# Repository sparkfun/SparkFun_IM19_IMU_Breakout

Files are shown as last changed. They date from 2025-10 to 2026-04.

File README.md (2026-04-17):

SparkFun 9DoF IMU Breakout - IM19
========================================

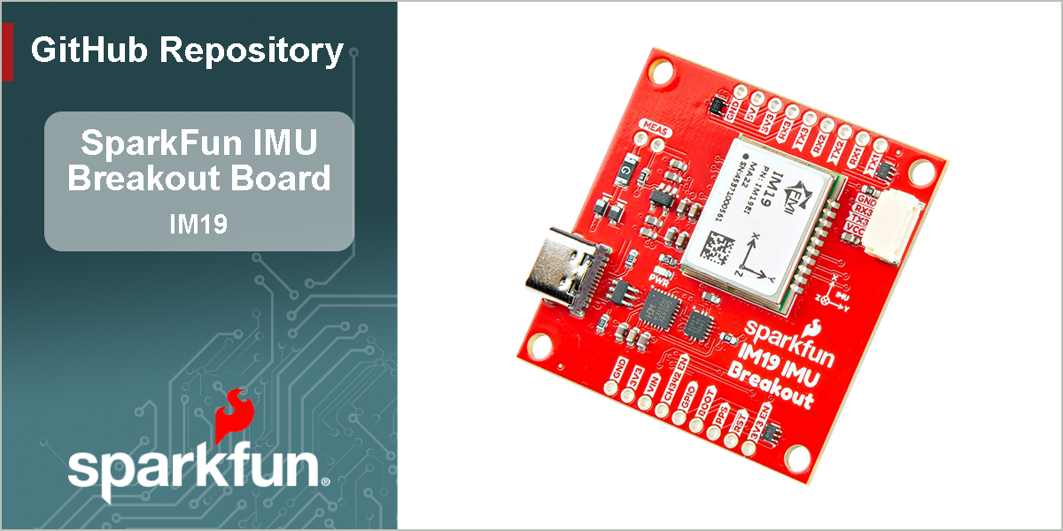
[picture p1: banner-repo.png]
SparkFun 9DoF IMU Breakout - IM19


[*SparkFun 9DoF IMU Breakout - IM19 (SEN-30381)*](https://www.sparkfun.com/sparkfun-9dof-imu-breakout-im19.html)

The Feyman (FMI) IM19 attitude module combines MEMS sensor data with GNSS RTK positioning data to provide high-precision attitude measurements. This enables advanced features, like tilt-compensated surveying and robust navigation through brief GNSS outages.

- **Survey-Grade Accuracy:** Delivers roll and pitch measurements accurate to within 0.05 degrees.
- **Tilt Compensation:** No more perfectly vertical survey poles! The IM19 can calculate a virtual digital level point at any tilt angle, revolutionizing field data collection.
- **Sensor Fusion:** Offers a continuous navigation solution (Dead Reckoning) even during brief GNSS signal loss, making it ideal for urban or obstructed environments.

When fed with NMEA **`GGA`**, **`GST`**, and **`RMC`** messages at **5Hz**, and a standard **Pulse-Per-Second timing signal**, the IM19 attitude module will output a proprietary NMEA ASCII `GPFMI` message which contains the compensated position of the tip of your surveying pole, plus the Roll, Pitch and Yaw of the IMU itself.

Our Breakout provides access to all three IM19 UART interfaces. `UART1` and `UART2` are accessible via a CH342 dual-channel USB-UART interface. `UART3` is accessible via a 4-pin locking JST connector. All three UARTs can be accessed via breadboard-compatible breakout pads too. The CH342 can be disconnected by simply pulling the `CH342_EN` breakout pad low; allowing full access to `UART1` and `UART2` via the breakout pads.

Power can be provided by USB, or the `VIN` (5V nominal) breakout pad. With care, you can also connect an external 3.3V supply to the `3V3` breakout pads or `Pin 1` of the JST connector. A jumper allows JST `Pin 1` to be configured for 5V input / output.

The IM19 attitude module is centered on the center of the PCB, simplifying your LEVER_ARM calculations. There is no X,Y offset to consider. The Z origin is 1.6mm above the top surface of the PCB (inside the IM19 module package); 3.2mm above the bottom surface of the PCB.

The 1.7" x 1.7" PCB is the same size as some of our RTK GNSS Boards, making it easy to stack the IM19 above or below your existing GNSS breakout board.

> [!NOTE]
> The IM19 needs to be fed with GNSS positioning data with a RTK Fixed solution *(RTK Fix)* in order to work correctly. This board will not work with non-RTK GNSS receivers.

Documentation
-------------

- **[Hookup Guide (docusaurus)](http://docs.sparkfun.com/SparkFun_IM19_IMU_Breakout/)** - A hookup guide for the SparkFun IM19 IMU breakout board hosted by GitHub pages.<br>
	 

Repository Contents
-------------------

- **[/docs](/docs/)** - Online documentation files
	- [/assets](/docs/assets/) - Assets files
		- [/3d_model](/docs/assets/3d_model/) - 3D models for the board
		- [/board_files](/docs/assets/board_files/) - Design files for the board
			- [KiCad Design Files](/docs/assets/board_files/kicad_files.zip) (.zip)
			- [Schematic](/docs/assets/board_files/schematic.pdf) (.pdf)
			- [Dimensions](/docs/assets/board_files/dimensions.pdf) (.pdf)
		- [/component_documentation](/docs/assets/component_documentation/) - Datasheets for hardware components
		- [/img/hookup_guide](/docs/assets/img/hookup_guide/) - Images for hookup guide documentation - Hookup guide images for the board
		- /Hardware - Hardware design files (.brd, .sch)
			- /Production - Production files

Product Variants
----------------

- [SEN-30381](https://www.sparkfun.com/sparkfun-9dof-imu-breakout-im19.html) - IM19 IMU Breakout

Version History
---------------

- [v10](https://github.com/sparkfun/SparkFun_IM19_IMU_Breakout/releases/tag/v10) - Initial Release

License Information
-------------------

This product is ***open source***!

Please review the [`LICENSE.md`](./LICENSE.md) file for license information.

If you have any questions or concerns about licensing, please contact technical support on our [SparkFun forums](https://community.sparkfun.com/).

Distributed as-is; no warranty is given.

- Your friends at SparkFun.

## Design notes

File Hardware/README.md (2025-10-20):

SparkFun <PRODUCT NAME> Design Files
=====================================

The .kicad_sch and .kicad_pcb files here are KiCad schematic and PCB design files from SparkFun Electronics.
KiCad can be found [here](https://www.kicad.org/).

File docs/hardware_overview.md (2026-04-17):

---
title: Hardware Overview
description: Overview of the board design, components, and interfaces
---

import Link from '@docusaurus/Link';

## Board Layout
The SparkFun 9DoF IMU Breakout - IM19 features the following:

<figure>
Layout
<figcaption>Layout of the major components on the breakout board.</figcaption>
</figure>

1. **[USB-C Connector](#usb-c-connector)**
:   The primary inteface for powering and interacting with the board
1. **[IM19 Attitude Module](#im19-attitude-module)**
:   The Feyman IM19 Attitude Module
1. **Header Pins**
:   Exposes pins to [power the board](#power) and breaks out the [interfaces of the IM19 attitude module](#io-pins)
1. **[JST Connector](#jst-connector)**
:   Exposes the `UART3` interface of the IM19 attitude module

## USB-C Connector
The USB connector is provided to power and interface with the IM19 attitude module. For most users, it will be the primary method for communicating with the IMU.

<figure>
USB-C Connector
<figcaption>The USB-C connector on the IM19 breakout board.</figcaption>
</figure>

### CH342 Converter
The [CH342 serial-to-USB converter](/component_documentation/CH342_Datasheet.pdf) allows users to interface with the `UART1` and `UART2` ports of the IM19 attitude module through the USB-C connector. The breakout board also includes a digital switch, to isolate the CH342 and allow users to access these UART ports through their breakout pins. To utilize the CH342, users may need to install a USB driver, which can be downloaded from the [manufacturer website](https://www.wch-ic.com/search?q=CH342&t=downloads). Once the USB driver is installed:

- Two virtual `COM` ports will be emulated, which can be used as standard `COM` ports to access the IM19 attitude module.
	- `Channel A`: `UART1` of the IM19 attitude module
	- `Channel B`: `UART2` of the IM19 attitude module

<figure>
CH342
<figcaption>The interface connections of the CH342 serial-to-USB converter.</figcaption>
</figure>

To activate the digital switch and utilize the UART ports through their breakout pins, users can [close the `CH342 EN` jumper](#jumpers) or pull the`CH342 EN` pin `LOW`. This disables the CH342 and disconnects the CH342 from the `UART1` and `UART2` ports of the IM19 attitude module, avoiding any bus contention issues.

::::tip[USB Drivers]

- <Icon icon="mdi:microsoft-windows" width="24" height="24" /> **Windows:** <Link className="button button--medium button--secondary" link="https://www.wch-ic.com/downloads/CH343SER_EXE.html"><Icon icon="octicon:download-16" width="16" height="16" /> Download Page for `CH343SER.EXE`</Link>
- <Icon icon="mdi:apple" width="24" height="24" /> **MacOS:** <Link className="button button--medium button--secondary" link="https://www.wch-ic.com/downloads/CH34XSER_MAC_ZIP.html"><Icon icon="octicon:download-16" width="16" height="16" /> Download Page for `CH341SER_MAC.ZIP`</Link>

:::info[Linux]
A USB driver is not required for Linux based operating systems.
:::

::::

## Power
The IM19 breakout board only requires **3.3V** to power all of the board's components. The simplest method to power the board is through the USB-C connector. Alternatively, the board can also be powered through the other connectors and [PTH](https://en.wikipedia.org/wiki/Through-hole_technology) pins.

<figure>
Power connections
<figcaption>IM19 breakout board's power connections.</figcaption>
</figure>

Below, is a general summary of the power circuitry on the board, broken out as [PTH](https://en.wikipedia.org/wiki/Through-hole_technology) pins:

- **`VUSB`** - The voltage from the USB-C connector, usually **5V**
	- Input Voltage Range: 4.4 - 5.5 V
	- Power source for the entire board
		- Powers the 3.3V voltage regulator (RT9080), which can source up to 600mA
		- When enabled, it can also power the [JST connector](#jst-connector) *(see the **[Jumpers](#jumpers)** section)*
- **`VIN`** - Alternate input supply voltage for the board
	- Input Voltage Range: 3.5 - 5.5V
	- Power source for the entire board
		- Powers the 3.3V voltage regulator (RT9080), which can source up to 600mA
		- When enabled, it can also power the [JST connector](#jst-connector) *(see the **[Jumpers](#jumpers)** section)*
- **`3V3`** - Provides a regulated 3.3V from the [RT9080](/component_documentation/RT9080.pdf), using the power supplied from the `VIN` pin or USB-C connector
	- Used to power the IM19 module, `PWR` LED, and the power pin of the [JST connector](#jst-connector)
	- Controlled by the `3V3 EN` pin, which is enabled by default
- **`3V3 EN`** - Enables the voltage output from the [RT9080](/component_documentation/RT9080.pdf), 3.3V voltage regulator
	- Enabled by default *(active `HIGH`)*
- **`RST`** - Used to reset the IM19 attitude module
	- Driving the pin `LOW` for 10ms triggers a restart of the IM19 module
- **`GND`** - The common ground or the 0V reference for the voltage supplies

:::info[Input Voltage]
While the [RT9080](/component_documentation/RT9080.pdf) LDO regulator has an input voltage range of 1.2 - 5.5V, a minimum supply voltage of **3.5V** is recommended for a 3.3V output.
:::

:::tip[JST Connector]
The `VCC` pin of the of the [JST connector](#jst-connector) is designed to operate as a voltage output. An input voltage can be supplied through the connector; however, users should be mindful of any voltage contention issues. Additionally, users can modify the [`VCC` jumper](#jumpers) to change the output voltage level of these pins.
:::

:::info
For more details, users can reference the [schematic](/board_files/schematic.pdf) and the datasheets of the individual components on the board.
:::

## IM19 Attitude Module
The [IM19 attitude module](/component_documentation/IM19EI_v1.4.1.pdf) from [Feyman Inc. (FMI)](http://feymani.com/en/) fuses MEMS IMU sensor data and GNSS RTK positioning to deliver high-precision attitude compensated measurements, with roll and pitch accurate to within 0.05 degrees. This kind of superb accuracy has widespread uses in industrial applications such as tilt RTK surveys (where RTK poles need not be held straight vertical as the IM19 can calculate a virtual digital level at any tilt angle), agriculture machine automation, and dead reckoning.

<iframe width="500" height="281" src="https://global.feymani.com/files/im19.mp4" type="video/mp4" title="IM19 product showcase" frameborder="0" allow="accelerometer; clipboard-write; encrypted-media; gyroscope; picture-in-picture" allowfullscreen></iframe>

**Features:**

- Power: 0.33W
	- Voltage Range: 3.0 to 3.6V
	- Current Consumption: 120 to 140mA
- Data Rate: 100Hz
- IMU Accuracy: &le;1% * D (1&sigma;, vehicle)
- Roll and Pitch: &le;0.02&deg; (1&sigma;)
- Heading/Yaw: &le;0.2&deg; (1&sigma;)
- Initialization: 1s (95%)
- Gyroscope
	- ARW: 0.17&deg;/&radic;(h)
	- Bias Stability: &plusmn;4.5&deg;/h
	- Range: &plusmn;1000&deg;/s
- Accelerometer
	- Speed RW: 0.04m/s/&radic;(h)
	- Bias Stability: &plusmn;0.3mg
	- Range: &plusmn;16g
- Self-calibration Technique

:::info
For more information, please refer to the [IM19 datasheet](/component_documentation/IM19.pdf).
:::

### Tilt-Compensation
In order to provide a tilt-compensated position, the IM19 attitude module requires the Pulse-Per-Second signal; receive NMEA GGA, RMC and GST messages on its `UART2` port, from a GNSS receiver with an RTK Fix; and be configured with information on the location of the GNSS antenna's reference center *(ARC)* and the survey point, with respect to the IMU's origin. Once calibrated, the IM19 will output proprietary `FMI*` messages containing the compensated position and roll, pitch and yaw attitudes.

<figure>
GNSS Integration
<figcaption>A GNSS receiver sending the required data to the IM19 attitude module.</figcaption>
</figure>

#### IMU Position
The measurements below are general guidelines for the position of the IMU inside the IM19 attitude module, with respect to the breakout board. The origin for the IMU is 2.72mm in Y-axis and 5.72mm in X-axis from the center of the IM19 attitude module. The plane of the Z-axis lies in the middle of IM19 attitude module, on the top surface of the module's PCB. In respect to the IM19 attitude module, which has a height of 3.2±0.1mm, the plane is located 1.6mm in towards the bottom/backside of the board from its top surface.

<figure>
IMU offset
<figcaption>The IMU origin, with respect to the IM19 attitude module and the PCB.</figcaption>
</figure>

<figure>
IMU offset height
<figcaption>The IMU origin, as viewed from the side of the IM19 IMU breakout board.</figcaption>
</figure>

In reference to the breakout board, the IMU's origin on the X/Y-axes is centered in the middle of the PCB. A reference mark is provided on the bottom of the IM19 IMU breakout board. From the reference mark, the plane of the Z-axis is located 3.2mm towards the top/front of the board. For the most precise measurements, users should also consider the manufacturing tolerances for the board as the position/orientation of the IM19 attitude module may shift in the reflow process and the edges of the PCB may not be precise. The PSB is panelized for production, along the edges with the header pins using a v-score.

<figure>
IMU origin marked
<figcaption>The IMU origin marked on the bottom of the IM19 IMU breakout board.</figcaption>
</figure>

#### Lever Arm and Club Vectors
With the origin point of the IMU in the IM19 attitude module, users can determine the vector to the `LEVER_ARM`. This vector runs from the origin point of the IMU to the `ARP` (antenna reference point) of the GNSS antenna. The `CLUB_VECTOR` runs from the `APC` (antenna phase center) of the GNSS antenna to the surveying marker point. Both the `CLUB_VECTOR` and `LEVER_ARM` vectors need to be configure in the IM19 attitude module before it can be calibrated.

<figure>
Vector points
<figcaption>The points for the `CLUB_VECTOR` and `LEVER_ARM` vector. (Source: [Septentrio](https://customersupport.septentrio.com/articles/Knowledge/ARP-APC-offsets))</figcaption>
</figure>

#### Calibration & Initialization
Once the IM19 attitude module has been configured, it must go through an initialization process to calibrate the module. As demonstrated in the videos below, user need to give the IM19 attitude module a vigorous shake to initialize the calibration process. Once initialized, users need to:

1. Shake to initialize calibration
1. Swing the module back and forth *(3-5sec)*
1. Rotate the device 90&deg;
1. Swing the module back and forth *(3-5sec)*
1. Done

<iframe width="500" height="281" src="https://www.youtube.com/embed/IWkgZUISF9M?start=47" title="IM19 Initialization Stability" frameborder="0" allow="accelerometer; autoplay; clipboard-write; encrypted-media; gyroscope; picture-in-picture" allowfullscreen></iframe>

<iframe width="500" height="281" src="https://www.youtube.com/embed/wND8cXVQSXo" title="IM19 Initialization Stability" frameborder="0" allow="accelerometer; autoplay; clipboard-write; encrypted-media; gyroscope; picture-in-picture" allowfullscreen></iframe>

#### Accuracy
When configured and calibrated, the IM19 attitude module can fuses IMU sensor and GNSS RTK positioning data to deliver compensated position. The accuracy, displayed in the table below, should also be considered when implemented.

| Tilt Angle | Accuracy |
| :---: | :---: |
| 0&deg; - 30&deg;  | 1cm |
| 30&deg; - 60&deg; | 2cm |

:::tip
It is recommended that the IM19 module is placed in a stable temperature region and avoid convection with the outside air.
:::

### I/O Pins
The headers on the board, breakout the I/O pins of the IM19 attitude module. The [UART interfaces](#uart-interfaces) of the IM19 are also connected to the [CH342 USB-to-serial converter](#ch342-converter) and [JST connector](#jst-connector) on the board.

<figure>
I/O pins
<figcaption>The I/O pins for the IM19 attitude module on breakout board.</figcaption>
</figure>

#### Pin Functions
Below is a summary of these I/O pins and their operation:

- `BOOT` - Start modes
	- `HIGH`: Boot mode
	- `NC` or `LOW`: Normal working mode
	- **Operation:** Pulling the `BOOT` pin `HIGH`, when powering up the module enables boot mode. This is used to update the module's firmware
- `RST` - Hardware reset pin
	- **Operation:** Pulling the `RST` pin `LOW` for 10ms, will reset module
- `GPIO` - Output IO
	- **Function:** Active buzzer can be connected
- UART Interfaces:
	- Baud rate: 115200bps
	- **Operation:** Configuration, message output, and firmware upgrade
	- **Configuration:** See [UART interface section](#uart-interfaces)
		- *Default Setting:*
			- *`UART2` - Connect GNSS board*
			- *`UART1`/`UART3` - Connect to host device*
- `PPS` - Connect to the PPS signal from the GNSS board
	- **Function:** Synchronizes the MEMS IMU sensor data with the GNSS RTK position data
	- **Configuration:** See [PPS signal section](#pps-pin)
		- *Default Setting: Falling edge*

## Header Pins
The headers on the board, breakout the [I/O pins of the IM19 attitude module](#io-pins), the [power pins](#power), [UART interfaces](#uart-interfaces), and `CH342_EN` UART control pin.

<figure>
Header pins
<figcaption>The header pins on the IM19 breakout board.</figcaption>
</figure>

### UART Interfaces
The three UART interfaces of the IM19 attitude module are broken out to the header pins on the board, the JST connector, and connected to the CH342 USB-to-serial converter. By default, `UART1` and `UART2` interfaces are attached to the [CH342 USB-to-serial converter](#ch342-converter) and are accessed through the [USB connector](#usb-c-connector). To utilize the `UART1` and `UART2` interfaces through their header pins, user need to toggle the `CH342_EN` pin or [close its jumper](#jumpers). This disables the [CH342 USB-to-serial converter](#ch342-converter) and a digital switch disconnects the UART interfaces to avoid any bus contention issues. Whereas, the `UART3` interface can be accessed through either the [JST connector](#jst-connector) or its header pins. The baud rate for the UART ports is not configurable and are set to **115200bps**.

<figure>
UART Interfaces
<figcaption>The UART interfaces of the IM19 breakout board.</figcaption>
</figure>

:::info[Settings and Configuration]
The UART ports are configured through [AT-commands](software_overview.md#at-commands), which are summarized below. However, it should be noted that the baud rate of the ports cannot be configured. By default, the baud rate is hard-coded to **115200bps**.

- **Baud Rate:** 115200bps
- **AT-Commands:**
	- `AT+NAVI_OUTPUT=<Port>,<Output>` - Enable the binary NAVI positioning output on the UART port
	- `AT+NASC_OUTPUT=<Port>,<Output>` - Enable the ASCII type NAVI positioning output on the UART port
	- `AT+MEMS_OUTPUT=<Port>,<Output>` - Enable the MEMS raw output on the UART port
	- `AT+GNSS_OUTPUT=<Port>,<Output>` - Enable the GNSS raw output on the UART port
	- `AT+GNSS_PORT=PHYSICAL_<Port>` - Sets the UART port for receiving the GNSS RTK data
		- Save the settings and restart the device to take effect
	- `AT+LOOP_BACK=<Loop>` - UART port enters or exits the loopback mode
	- `AT+OUTPUT_DISABLE=<Port>` - Disables all output messages from the UART port
	- Where the `<values>` above should be:
		- `<Port>` = `UART1`, `UART2`, or `UART3`
		- `<Loop>` = `UART1`, `UART2`, `UART3`, or `NONE`
		- `<Output>` = `ON` or `OFF`

:::

::::note
By default, the `UART2` port is configured to receive the GNSS data required for the tilt-compensation. Whereas the default configuration of the `UART1` and `UART3` ports, the ports have the same functions. They can be connected to the main processor an/or used as a debugging, firmware upgrade, or configuration interface.

- `UART1` - Connect to host device
	- Configuration, message output, and firmware upgrade
- `UART2` - Connect GNSS board
- `UART3` - Connect to host device
	- Configuration, message output, and firmware upgrade

<figure>
System Integration
<figcaption>System integration of the IM19 breakout board, with the default configuration.</figcaption>
</figure>

:::info
For the UART interface sending the GNSS messages to the IM19 breakout board, users will need to configure the UART port with the following settings:

- Baudrate: 115200bps
- Output NMEA Messages: `GPGGA`, `GPRMC`, and `GPGST`
- Solution Rate: **5Hz**

:::
::::

### PPS Pin
The `PPS` pin needs to be connected to the PPS signal from the GNSS receiver. It is utilized to synchronizes the MEMS IMU sensor data with the GNSS RTK position data. When connected, the `AT+CHECK_SYNC` AT-command can be used to verify if the IM19 attitude module is synchronized with the GNSS RTK position data.

<figure>
PPS pin
<figcaption>The `PPS` pin on the IM19 breakout board.</figcaption>
</figure>

:::info
The `AT+SET_PPS_EDGE` AT-command configures the edge detection parameter for the PPS signal. By default, the IM19 attitude module is configured to detect the falling-edge of the PPS signal.
:::

### Boot/RST Pins
The `BOOT` and `RST` pins are, respectively, used to update or reset the IM19 attitude module.

- The `BOOT` pin can be toggled `HIGH`, when powering up the IM19 breakout board. This enables boot mode to update the IM19 attitude module's firmware through the UART interface.
- The `RST` pin can be pulled `LOW` for 10ms to IM19 attitude module.

<figure>
Boot and reset pins
<figcaption>The `BOOT` and `RST` pins on the IM19 breakout board.</figcaption>
</figure>

### GPIO Pin
The `GPIO` pin is an ouput pin; its suggested use is an audio indicator, with a connected buzzer.

<figure>
GPIO pin
<figcaption>The `GPIO` pin on the IM19 breakout board.</figcaption>
</figure>

## JST Connector
The JST-GH connector is used to access the [`UART3` interface](#uart-interfaces). Its pin layout is labeled on the board and listed in the diagram below. The power supply for the `VCC` pin can be configured using the [`VCC` jumper](#jumpers) on the bottom of the board. By default, the jumper is configured to supply **3.3V** to the JST connector.

<figure>
JST connector
<figcaption>The JST-GH connector on the IM19 breakout board.</figcaption>
</figure>

:::note
When connecting the IM19 breakout board to other products, users should be aware of the pin connections between the devices. The table below, details the pin connections of the locking JST connector on the IM19 breakout board.

<figure>
JST connector pin layout
<figcaption>The pin layout of the JST connector on the IM19 breakout board.</figcaption>
</figure>

<table>
<tr>
<th>Pin Number</th>
<td>
	**1**<br />
	*(Left Side)*
</td>
<td>**2**</td>
<td>**3**</td>
<td>
    **4**<br />
	*(Right Side)*
</td>
</tr>
<tr>
<th>Label</th>
<td>`VCC`</td>
<td>`TX3`</td>
<td>`RX3`</td>
<td>`GND`</td>
</tr>
<tr>
<th>Function</th>
<td>
	<u>**Voltage Output**</u>
    <ul>
    <li>**Default: 3.3V**</li>
	<li>3.3V or 5V</li>
    </ul>
</td>
<td>`UART3` - Receive</td>
<td>`UART3` - Transmit</td>
<td>Ground</td>
</tr>
</table>

:::

:::tip[Baud Rate]
Users will need to configure the baud rate of the attach devices to match the UART port of the IM19 attitude module, which are set to **115200bps**.
:::

## Status LEDs
There is a red `PWR` status LED on the IM19 breakout board, which indicates when the board is powered. It turns on once 3.3V power is supplied to the board

<figure>
Status LEDs
<figcaption>The `PWR` status LED indicator on the IM19 breakout board.</figcaption>
</figure>

## Jumpers

:::note[Never modified a jumper before?]
Check out our [Jumper Pads and PCB Traces tutorial](https://learn.sparkfun.com/tutorials/664) for a quick introduction!
:::

There are five jumpers on these board that can be used to easily modify the hardware connections.

<figure>
Jumpers
<figcaption>The jumpers on the bottom of the BlueSMiRF v2.</figcaption>
</figure>

- **`SHLD`** - This jumper can be cut to disconnect the shield of the USB-C connector from the board's ground plane.
- **`PWR`** - This jumper can be cut to remove power from the red, power LED.
- **`MEAS`** - This jumper can be cut to to measure the current coming into the board from the USB connector or `VIN` pin.
- **`VCC`** - This jumper can be modified to configure/disconnect the `VCC` pin of the [4-pin locking JST connector](#jst-connector) to/from `3V3` or `5V` power.
	- By default, the jumper is configured to supply 3.3V.
- **`CH342_EN`** - This jumper can be closed to disable the CH342 and disconnect it from the `UART1` and `UART2` ports of the IM19 attitude module. 
	- Allows the breakout pins to be utilized; avoiding bus contention issues.

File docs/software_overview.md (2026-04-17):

---
title: Software Overview
description: A guide on recommended software
---

import Link from '@docusaurus/Link';

## CH342 USB Driver
The USB drivers for the CH342 USB-to-Serial converter can be downloaded from the [manufacturer's website](https://www.wch-ic.com/search?q=CH342&t=downloads).

- <Icon icon="mdi:microsoft-windows" width="24" height="24" /> **Windows:** <Link className="button button--medium button--secondary" link="https://www.wch-ic.com/downloads/CH343SER_EXE.html"><Icon icon="octicon:download-16" width="16" height="16" /> Download Page for `CH343SER.EXE`</Link>
- <Icon icon="mdi:apple" width="24" height="24" /> **MacOS:** <Link className="button button--medium button--secondary" link="https://www.wch-ic.com/downloads/CH34XSER_MAC_ZIP.html"><Icon icon="octicon:download-16" width="16" height="16" /> Download Page for `CH341SER_MAC.ZIP`</Link>

:::info[Linux]
A USB driver is not required for Linux based operating systems.
:::

Once the USB driver is installed, two virtual `COM` ports will be emulated, which can be used as standard `COM` ports to access UART interfaces of the IM19 attitude module.

- `Channel A`: `UART1` of the IM19 attitude module
- `Channel B`: `UART2` of the IM19 attitude module

:::info[Default Settings]
The UART ports of the IM19 attitude module have the following default configuration:

- Baud Rate: 115200bps
- Data Bits: 8
- Parity: No
- Stop Bits: 1

:::

:::tip
The breakout board also includes a digital switch, to isolate the CH342 and allow users to access these UART ports through their breakout pins. To activate the digital switch and utilize the UART ports through their breakout pins, users can [close the `CH342 EN` jumper](hardware_overview.md#jumpers) or pull the`CH342 EN` pin `LOW`. This disables the CH342 and disconnects the CH342 from the `UART1` and `UART2` ports of the IM19 attitude module, avoiding any bus contention issues.
:::

## AT-Commands
Below is a summary of the AT commands supported by the IM19 attitude module. The AT-commands are case-sensitive and need to be sent in a single string; therefore, when using a terminal emulator, it is recommended to utilize one that sends a string of characters instead of each character as they are typed.

| AT Command | Description |
| :--- | :--- |
| `AT+SYSTEM_RESET` | System reset |
| `AT+SAVE_ALL` | Save the parameters |
| `AT+UPDATE_APP` | Update module firmware, see attachment for protocols |
| `AT+UPDATE_BOOT` | Update Bootloader，see attachment for protocols |
| `AT+GNSS_CARD=` | Set the GNSS RTK receiver type:<ul><li>`HEMI`, `NOVTEL`, `UNICORE`, `OEM`</li></ul> |
| `AT+READ_PARA=SYSTEM/ALL` | Read parameters (`SYSTEM` or `ALL`) |
| `AT+LOAD_DEFAULT` | Loads default parameters |
| `AT+AUTO_FIX=ENABLE/DISABLE` | Installation angle estimation in tilt measurement applications |
| `AT+CLUB_VECTOR=X,Y,Z` | Set the RTK pole vector to map the position to the end of the RTK pole *(units in meters)* |
| `AT+NAVI_OUTPUT=UARTn,ON/OFF` | Binary NAVI positioning output for `UARTn` |
| `AT+NASC_OUTPUT=UARTn,ON/OFF` | Ascii type NAVI positioning output for `UARTn` |
| `AT+MEMS_OUTPUT=UARTn,ON/OFF` | MEMS raw output for `UARTn` |
| `AT+GNSS_OUTPUT=UARTn,ON/OFF` | GNSS raw output for `UARTn` |
| `AT+LEVER_ARM=X,Y,Z` | Set the lever arm *(units in meters)* |
| `AT+LEVER_ARM2=X,Y,Z` | Set the lever arm, the input value will be automatically adjusted according to the estimated installation angle *(units in meters)* |
| `AT+CHECK_SYNC` | Query whether time is synchronized between MEMS and GNSS |
| `AT+HIGH_RATE=ENABLE/DISABLE` | High-rate mode setting |
| `AT+ACTIVATE_KEY=KEY` | Module activation |
| `AT+ALIGN_VEL=1.0` | Set the initial alignment speed threshold |
| `AT+VERSION` | Query the Firmware version |
| `AT+GNSS_PORT=PHYSICAL_UARTn` | Set the physical serial port on `UARTn`, for communicating with the GNSS RTK receiver. Save the Settings and restart to take effect |
| `AT+WORK_MODE=X` | Set the module working mode |
| `AT+INSTALL_ANGLE=X,Y,Z` | Set the module installation angle *(units in degrees)* |
| `AT+THIS_PORT` | Query the serial port number |
| `AT+FILTER_STOP=ENABLE/DISABLE` | Causes the filter to enter or exit stop mode |
| `AT+LOOP_BACK=UARTn/NONE` | `UARTn` enters or exits the loopback mode |
| `AT+FILTER_RESET` | Filter Reset |
| `AT+CHECK_CRC=N` | The IM19EE firmware CRC is calculated for checking the firmware, where `N` is the firmware size |
| `AT+CORRECT_HOLDER=ENABLE/DISABLE` | Turn on or off RTK pole length compensation |
| `AT+OUTPUT_DISABLE=UARTxn` | Disable the output of all messages over the serial port `UARTn` |
| `AT+CALIBRATE_MODE2=STEP1/STEP2` | Factory calibration command |
| `AT+SET_CHECK_LEVEL=LEVELx` | Set check level of calibration parameter |
| `AT+FACTORY_PARA_x=X,Y,Z` | Recovery factory calibration parameter |
| `AT+SET_PPS_EDGE=RISING/FALLING` | Set PPS edge, accept falling pps edge by default |

:::info
For more information, please reference the [IM19 integration manual](/component_documentation/IM19EI_v1.4.1.pdf).
:::

## Compatible Software
Below are some compatible software options for configuring the IM19 attitude module and receiving the tilt-compensated position in its proprietary message format.

### PyGPSClient
As of [v1.5.8](https://github.com/semuconsulting/PyGPSClient/releases/tag/v1.5.8), a widget has been added to the [PyGPSClient](https://github.com/semuconsulting/PyGPSClient) application to configure and utilize the IM19 attitude module.

:::info[Resources]
For additional information, users can refer to the following resources for the PyGPSClient software:

- [GitHub Repository](https://github.com/semuconsulting/PyGPSClient)
- [Installation Instructions](https://github.com/semuconsulting/PyGPSClient?tab=readme-ov-file#installation)
- [PyPI Project](https://pypi.org/project/pygpsclient/)

:::

#### Installation
There are a variety of [installation methods](https://github.com/semuconsulting/PyGPSClient?tab=readme-ov-file#installation) detailed in the GitHub repository's `README.md` file. However, we recommend utilizing the `pip` installation method.

::::info[Installation Commands]
Depending on how Python is installed on the computer, one of the following commands should allow users to install the software.

- ```bash
	python3 -m pip install pygpsclient
	```

- ```bash
	pip install pygpsclient
	```

:::note[System Requirements]
This installation method requires an internet connection. Additionally, users will also need administrative privileges *(or root access `sudo`)* for the installation.
:::

::::

#### Device Connection
Before users can connect to the IM19 breakout board, they will need to specify the settings of the UART port in PyGPSClient. Once configured, users can select the <kbd><Icon icon="material-symbols:usb" width="24" height="24" /></kbd> button and PyGPSClient will automatically attempt to connect to the GNSS module.

- Below, is a list of the default settings for `UART` ports of the IM19. These settings should be selected in the configuration menu.
- For the `Serial Port`, select the port associated with the attached UART interface.

<figure>
UART Settings in PyGPSClient
<figcaption>Specify the settings for the UART port in PyGPSClient.</figcaption>
</figure>

:::info[Default Settings]
The UART ports of the IM19 attitude module have the following default configuration:

- Baud Rate: 115200bps
- Data Bits: 8
- Parity: No
- Stop Bits: 1

:::

### Arduino IDE
Most users may already be familiar with the Arduino IDE and its use. However, for those of you who have never heard the name *Arduino* before, feel free to check out the [Arduino website](https://www.arduino.cc/en/Guide/HomePage). To get started with using the Arduino IDE, check out our tutorials below:

- [What is an Arduino?](https://learn.sparkfun.com/tutorials/50)
- [Installing the Arduino IDE](https://learn.sparkfun.com/tutorials/61)
- [Installing an Arduino Library](https://learn.sparkfun.com/tutorials/15)
- [Installing Board Definitions in the Arduino IDE](https://learn.sparkfun.com/tutorials/1265)

#### IM19 IMU Arduino Library
The [SparkFun IM19 Tilt Sensor Arduino Library](https://github.com/sparkfun/SparkFun_IM19_IMU_Arduino_Library) can be installed from the library manager in the Arduino IDE by searching for:

```txt
SparkFun IM19 IMU Arduino Library
```

<figure>
Library listed in the library manager of the Arduino IDE
<figcaption>SparkFun IM19 IMU Arduino Library in the library manager of the Arduino IDE.</figcaption>
</figure>

:::info[Manually Download the Arduino Library]
For users who would like to manually download and install the library, the `*.zip` file can be accessed from the [GitHub repository](https://github.com/sparkfun/SparkFun_IM19_IMU_Arduino_Library) or downloaded by clicking the button below.

<p className="text--center">
<Link className="button button--medium button--primary" link="https://github.com/sparkfun/SparkFun_IM19_IMU_Arduino_Library/archive/refs/heads/main.zip"><Icon icon="octicon:download-16" width="16" height="16" /> Download the Arduino Library</Link>
</p>

:::

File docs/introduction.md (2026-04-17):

---
title: Introduction
slug: /
---

<figure>
Hookup Guide - Thumbnail
</figure>

# Introduction
The Feyman (FMI) IM19 attitude module combines MEMS sensor data with GNSS RTK positioning data to provide high-precision attitude measurements. This enables advanced features, like tilt-compensated surveying and robust navigation through brief GNSS outages.

- **Survey-Grade Accuracy:** Delivers roll and pitch measurements accurate to within 0.05 degrees.
- **Tilt Compensation:** No more perfectly vertical survey poles! The IM19 can calculate a virtual digital level point at any tilt angle, revolutionizing field data collection.
- **Sensor Fusion:** Offers a continuous navigation solution (Dead Reckoning) even during brief GNSS signal loss, making it ideal for urban or obstructed environments.

When fed with NMEA **`GGA`**, **`GST`**, and **`RMC`** RTK corrected, GNSS messages at **5Hz**, and a standard **Pulse-Per-Second signal**, the IM19 attitude module will output a proprietary NMEA ASCII `GPFMI` message which contains the compensated position of the tip of your surveying pole, plus the Roll, Pitch and Yaw of the IMU itself.

:::note
The IM19 needs to be fed with GNSS positioning data with a RTK Fixed solution *(RTK Fix)* in order to work correctly. This board will not work with non-RTK GNSS receivers.
:::

## Required Materials
In this guide we'll cover how to setup the IM19 breakout board. To follow along with this tutorial, at a minimum, users will need the following items:

- Computer with an operating system (OS) that is compatible with all the [software installation requirements](software_overview.md#compatible-software)
- USB cables
- RTK GNSS receiver
	- GNSS antenna
- Hookup wires

## Sections
Jump to a specific section of the hookup guide:

<DocCardList
	items={
		[
			{
				type: 'link',
				label: 'Hardware Overview',
				description: 'Overview of the board design, components, and interfaces',
				href: 'hardware_overview',
				customProps: { iconify: 'mdi:integrated-circuit' },
			},
			{
				type: 'link',
				label: 'Hardware Assembly',
				description: 'Instructions on product integration',
				href: 'hardware_assembly',
				customProps: { iconify: 'material-symbols:precision-manufacturing' },
			},
			{
				type: 'link',
				label: 'Software Overview',
				description: 'A guide on recommended software',
				href: 'category/software',
				customProps: { iconify: 'fa7-solid:computer' },
			},
			{
				type: 'link',
				label: 'Resources',
				description: 'Design files, schematic, datasheets, manuals, software resources, etc.',
				href: 'resources',
				customProps: { iconify: 'mdi:folder-file-outline' },
			},
			{
				type: 'link',
				label: 'Troubleshooting TIps',
				description: 'A compilation of support tips for this product',
				href: 'troubleshoot',
				customProps: { iconify: 'mdi:lightbulb-on' },
			},
		]
	}
/>

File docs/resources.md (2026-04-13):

---
title: Product Resources
description: Design files, schematic, datasheets, manuals, software resources, etc.
---

## Product Resources

- <Icon icon="simple-icons:sparkfun" width="16" height="16" /> [Product Page](https://www.sparkfun.com/sparkfun-9dof-imu-breakout-im19.html)
- <Icon icon="mdi:folder-cog" width="16" height="16" /> Design Files:
	- <Icon icon="fa7-solid:file-pdf" width="16" height="16" /> [Board Dimensions](/board_files/dimensions.pdf)
	- <Icon icon="fa7-solid:file-pdf" width="16" height="16" /> [Schematic](/board_files/schematic.pdf)
	- <Icon icon="mdi:folder-zip" width="16" height="16" /> [KiCad Files](/board_files/kicad_files.zip)
	- <Icon icon="mdi:rotate-3d" width="16" height="16" /> [STEP File](/3d_model/cad_model.step)
- <Icon icon="simple-arduino" width="16" height="16" /> [SparkFun IM19 Tilt Sensor Arduino Library](https://github.com/sparkfun/SparkFun_IM19_IMU_Arduino_Library)
- Component Documentation
	- <Icon icon="fa7-solid:file-pdf" width="16" height="16" /> [IM19 Datasheet](/component_documentation/IM19.pdf)
		- <Icon icon="fa7-solid:file-pdf" width="16" height="16" /> [IM19 Product Integration Guide](/component_documentation/IM19EI_v1.4.1.pdf)
	- <Icon icon="fa7-solid:file-pdf" width="16" height="16" /> [JST-GH Connector Datasheet](/component_documentation/JST-GH_datasheet.pdf)
	- <Icon icon="fa7-solid:file-pdf" width="16" height="16" /> [RT9080 Datasheet](/component_documentation/RT9080.pdf)
- <Icon icon="mdi:github" width="16" height="16" /> [Hardware Repo](https://github.com/sparkfun/SparkFun_IM19_IMU_Breakout)

## 🏭&nbsp;Manufacturer's Resources
Feyman Inc. also provides some resources for the IM19 attitude module:

- <Icon icon="mdi:web" width="16" height="16" /> [IM19 Product Page](https://global.feymani.com/product/attitede/im19ee/)
	- <Icon icon="mdi:newspaper-variant" width="16" height="16" /> [Documentation](https://global.feymani.com/document/)
- <Icon icon="mdi:web" width="16" height="16" /> [IM19 Product Page](http://feymani.com/en/show-53-2-1.html) *(alternate website)*
- <Icon icon="mdi:youtube" width="16" height="16" /> [Feyman Inc. YouTube Channel](https://www.youtube.com/@FeymanIncFMI)

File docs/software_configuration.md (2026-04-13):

---
title: Device Configuration
description: Instructions on the device configuration and utilization
---

## Reset Factory Defaults
Below are the AT-commands to check and restore settings to the factory defaults:

| AT Command | Description |
| :--- | :--- |
| `AT+READ_PARA=SYSTEM/ALL` | Read parameters (`SYSTEM` or `ALL`) |
| `AT+LOAD_DEFAULT` | Loads default parameters |
| `AT+FACTORY_PARA_x=X,Y,Z` | Recovery factory calibration parameter |

:::tip[Save & Reset]
Don't forget to save the changes and reset the device:

| AT Command | Description |
| :--- | :--- |
| `AT+SAVE_ALL` | Save the parameters |
| `AT+SYSTEM_RESET` | System reset |

:::

## Tilt-Compensation
Below are the AT-commands to configure the tilt-compensation settings:

| AT Command | Description |
| :--- | :--- |
| `AT+GNSS_CARD=` | Set the GNSS RTK receiver type:<ul><li>`HEMI`, `NOVTEL`, `UNICORE`, `OEM`</li></ul> |
| `AT+GNSS_PORT=PHYSICAL_UARTn` | Set the physical serial port on `UARTn`, for communicating with the GNSS RTK receiver. Save the Settings and restart to take effect |

| AT Command | Description |
| :--- | :--- |
| `AT+CLUB_VECTOR=X,Y,Z` | Set the RTK pole vector to map the position to the end of the RTK pole *(units in meters)* |
| `AT+LEVER_ARM=X,Y,Z` | Set the lever arm *(units in meters)* |
| `AT+LEVER_ARM2=X,Y,Z` | Set the lever arm, the input value will be automatically adjusted according to the estimated installation angle *(units in meters)* |
| `AT+INSTALL_ANGLE=X,Y,Z` | Set the module installation angle *(units in degrees)* |

:::tip[Save & Reset]
Don't forget to save the changes and reset the device:

| AT Command | Description |
| :--- | :--- |
| `AT+SAVE_ALL` | Save the parameters |
| `AT+SYSTEM_RESET` | System reset |

:::

## Output Messages
Below are the AT-commands to enable the message outputs of a UART port:

| AT Command | Description |
| :--- | :--- |
| `AT+NAVI_OUTPUT=UARTn,ON/OFF` | Binary NAVI positioning output for `UARTn` |
| `AT+NASC_OUTPUT=UARTn,ON/OFF` | Ascii type NAVI positioning output for `UARTn` |
| `AT+MEMS_OUTPUT=UARTn,ON/OFF` | MEMS raw output for `UARTn` |
| `AT+GNSS_OUTPUT=UARTn,ON/OFF` | GNSS raw output for `UARTn` |
| `AT+OUTPUT_DISABLE=UARTxn` | Disable the output of all messages over the serial port `UARTn` |
| `AT+THIS_PORT` | Query the serial port number |

:::tip[Save & Reset]
Don't forget to save the changes with the `AT+SAVE_ALL` AT-command.
:::

## Device

| AT Command | Description |
| :--- | :--- |
| `AT+CHECK_SYNC` | Query whether time is synchronized between MEMS and GNSS |
| `AT+CORRECT_HOLDER=ENABLE/DISABLE` | Turn on or off RTK pole length compensation |

:::tip[Save & Reset]
Don't forget to save the changes with the `AT+SAVE_ALL` AT-command.
:::

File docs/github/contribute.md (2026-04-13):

---
title: Contribute
description: Feel free to contribute to our open-source design and documentation
---

## Make an Augmentation!
Spot an improvement opportunity? Feel free to contribute to our open-source design and documentation. 

## Improve our Documentation
All of this documentation can be modified by you! Please help us make it better.

- These pages are contained in the [`docs` folder](https://github.com/sparkfun/SparkFun_IM19_IMU_Breakout/tree/main/docs) of the [SparkFun IM19 IMU Breakout repository](https://github.com/sparkfun/SparkFun_IM19_IMU_Breakout).

### Submit a Correction

1. With a GitHub account, [fork this repository](https://github.com/sparkfun/SparkFun_IM19_IMU_Breakout/fork).
2. Add your corrections or improvements to the markdown file.
3. File a pull request with your changes, and enjoy making the ~~words~~ ~~worlds~~ world a better place.
	- Once received, the documentation specialist will automatically be notified.
	- We will review your suggested improvements to make sure they are correct and fit within our documentation standards.

## Improve our Hardware Design
All of our designs are open-source! Please help us make it better.

- Our board design files are contained in the `/Hardware` directories of the [SparkFun IM19 IMU Breakout repository](https://github.com/sparkfun/SparkFun_IM19_IMU_Breakout).

### Submit a Design Enhancement

1. With a GitHub account, [fork this repository](https://github.com/sparkfun/SparkFun_IM19_IMU_Breakout/fork).
2. Add your design augmentation(s)
3. File a pull request with your changes, and enjoy making the ~~words~~ ~~worlds~~ world a better place.
	1. Once received, the engineer in charge of the original design will automatically be notified.
	2. We will review your suggested improvement(s) to verify that they are within our board design standards and meet our product design requirements.
	3. If approved, we will flag these changes for our next board revision. Congrats! 🍻

		!!! info
			Even if your suggestion is accepted, these changes may not be immediately available for purchase. We may have to cycle through our current product inventory first.

## Contributors
Let's provide some recognition to the contributors for this project!

GitHub Contributors Image
<br/>


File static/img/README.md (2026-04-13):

img directory
====================
This folder should contain the images for the product documentation

General Images
--------------

- `favicon.ico` - SparkFun flame logo (favicon)
- `banner-*` - Banner images hookup guide

Directory
---------

- `graphical_datasheet` - Files to generate graphical datasheet
- `hookup_guide` - Images for the hookup guide pages
- `qr_code` - QR code images
- `qwiic` - Images for Qwiic Banner

QR Codes
--------

- [QR code generator](https://qrgenerator.org/)
	- Flame Color: #E0311D
	- Frame Color: #3C464D
- [Remove meta data from svg](https://jakearchibald.github.io/svgomg/)

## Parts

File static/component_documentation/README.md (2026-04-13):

SparkFun Documentation
=======================
This directory should include any necessary datasheets, example number crunching, etc.

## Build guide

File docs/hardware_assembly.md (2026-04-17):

---
title: Hardware Assembly
description: Instructions for product integration
---

## Recommended Setup
By default, the `UART2` port is configured to receive the GNSS data required for the tilt-compensation. Whereas the default configuration of the `UART1` and `UART3` ports, the ports have the same functions. They can be connected to the main processor an/or used as a debugging, firmware upgrade, or configuration interface.

- `UART1` - Connect to host device
	- Configuration, message output, and firmware upgrade
- `UART2` - Connect GNSS board
- `UART3` - Connect to host device
	- Configuration, message output, and firmware upgrade

<figure>
System Integration
<figcaption>System integration of the IM19 breakout board, with the default configuration.</figcaption>
</figure>

:::info
For the UART interface sending the GNSS messages to the IM19 breakout board, users will need to configure the UART port with the following settings:

- Baudrate: 115200bps
- Output NMEA Messages: `GPGGA`, `GPRMC`, and `GPGST`
- Solution Rate: **5Hz**

:::

## USB Connector
The USB connection can be utilized for serial communication and configuring the IM19 attitude module. Users only need to connect their IM19 breakout board to a computer, using a USB-C cable.

<figure>
IM19 breakout board USB connection
<figcaption>The IM19 breakout board with USB cable attached.</figcaption>
</figure>

## JST Connector
The JST connector on the IM19 board, breaks out the `UART3` port of the IM19 attitude module. In certain circumstances, users want to utilize the JST connector to attach one of our radios or [BlueSMiRF](https://www.sparkfun.com/sparkfun-bluesmirf-v2-jst.html).

Radio Transceivers and Cables

- [SiK Telemetry Radio V3 - 915MHz, 100mW](https://www.sparkfun.com/sik-telemetry-radio-v3-915mhz-100mw.html)
- [SparkFun LoRaSerial Kit - 915MHz (Enclosed)](https://www.sparkfun.com/sparkfun-loraserial-kit-915mhz-enclosed.html)
- [BlueSMiRF - JST](https://www.sparkfun.com/sparkfun-bluesmirf-v2-jst.html)
- [JST-GHR-04V to JST-GHR-06V Cable - 1.25mm pitch](https://www.sparkfun.com/jst-ghr-04v-to-jst-ghr-06v-cable-1-25mm-pitch.html)
- [GHR-04V-S to GHR-06V-S Cable - 100mm](https://www.sparkfun.com/ghr-04v-s-to-ghr-06v-s-cable-100mm.html)

<figure>
Device connected to the JST connector
<figcaption>The [Telemetry Radio v3](https://www.sparkfun.com/sik-telemetry-radio-v3-915mhz-100mw.html) connected to the IM19 breakout.</figcaption>
</figure>

:::info
Users can [modify the `VCC` jumper](hardware_overview.md#jumpers) on the back of the board to enable a 5V output on the `VCC` pin.
:::

:::note
When connecting the IM19 breakout board to other products, users should be aware of the pin connections between the devices. The table below, details the pin connections of the locking JST connector on the IM19 breakout board.

<figure>
JST connector pin layout
<figcaption>The pin layout of the JST connector on the IM19 breakout board.</figcaption>
</figure>

<table>
<tr>
<th>Pin Number</th>
<td>
	**1**<br />
	*(Left Side)*
</td>
<td>**2**</td>
<td>**3**</td>
<td>
    **4**<br />
	*(Right Side)*
</td>
</tr>
<tr>
<th>Label</th>
<td>`VCC`</td>
<td>`TX3`</td>
<td>`RX3`</td>
<td>`GND`</td>
</tr>
<tr>
<th>Function</th>
<td>
	<u>**Voltage Output**</u><br />
    - **Default: 3.3V**
	- 3.3V or 5V
</td>
<td>`UART3` - Receive</td>
<td>`UART3` - Transmit</td>
<td>Ground</td>
</tr>
</table>

:::

::::tip[Baud Rate]
Users will need to configure the baud rate of the attach devices to match the UART port of the IM19 attitude module, which are set to **115200bps**.

:::info
As documented in the [LoRaSerial product manual](https://docs.sparkfun.com/SparkFun_LoRaSerial), the baud rate for these radios are configured by the [`SERIAL_SPEED` parameter](https://docs.sparkfun.com/SparkFun_LoRaSerial/at_commands/#serial-commands). The default configuration is `SERIAL_SPEED`: **57600bps**.
:::

::::

## Breakout Pins
The [PTH](https://en.wikipedia.org/wiki/Through-hole_technology) pins on the IM19 board are broken out into 0.1"-spaced pins on the outer edges of the board.

:::warning
The board's pin layout is similar to some of our GNSS breakout boards and can be stacked using headers. However, users will need to configure the `GNSS_PORT` to the appropriate UART interface.
:::

:::note[New to soldering?]
If you have never soldered before or need a quick refresher, check out our [How to Solder: Through-Hole Soldering](https://learn.sparkfun.com/tutorials/how-to-solder-through-hole-soldering) guide.
:::

:::tip
The breakout board also includes a digital switch, to isolate the CH342 and allow users to access the `UART1` and `UART2` ports of the IM19 attitude module through their breakout pins. To activate the digital switch and utilize the UART ports through their breakout pins, users can [close the `CH342 EN` jumper](hardware_overview.md#jumpers) or pull the`CH342 EN` pin `LOW`. This disables the CH342 and disconnects the CH342 from the `UART1` and `UART2` ports of the IM19 attitude module, avoiding any bus contention issues.
:::

### Headers
When selecting headers, be sure you are aware of the functionality you require.

<figure>
Soldering headers
<figcaption>Soldering headers to the IM19 breakout board.</figcaption>
</figure>

### Hookup Wires
For a more permanent connection, users can solder wires directly to the board.

<figure>
Soldering wires
<figcaption>Soldering wires to the IM19 breakout board.</figcaption>
</figure>

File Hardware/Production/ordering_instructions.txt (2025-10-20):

Ordering Instructions:
Panel dimensions: 167.10 x 100.56 mm.
Controlled Impedance: JLC7628
Material: TG135
Solder Mask: Red
Silkscreen Color: White
Layers: 4
Finish: ENIG
Thickness: 1.6mm
Inner Copper Weight: 0.5oz
Outer Copper Weight: 1oz
Minimum track width: 0.18mm (7.00mil)
Minimum via drill: 0.30mm (12.00mil)
No Clean Process

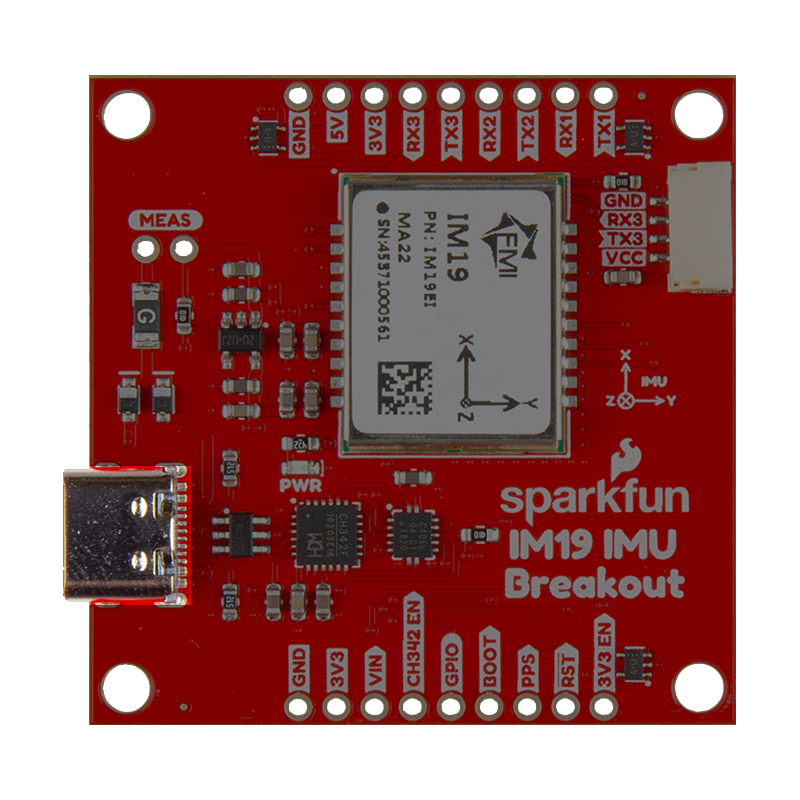
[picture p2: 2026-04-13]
static/img/hookup_guide/usb_connector.png

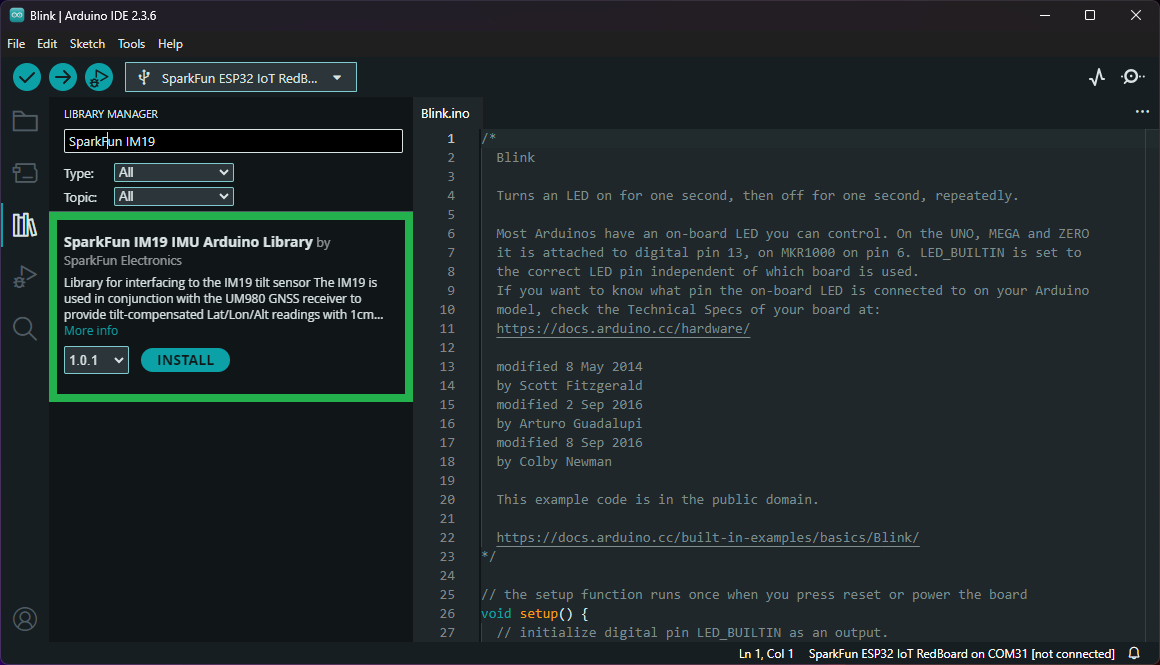
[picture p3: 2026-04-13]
static/img/hookup_guide/arduino_library.png

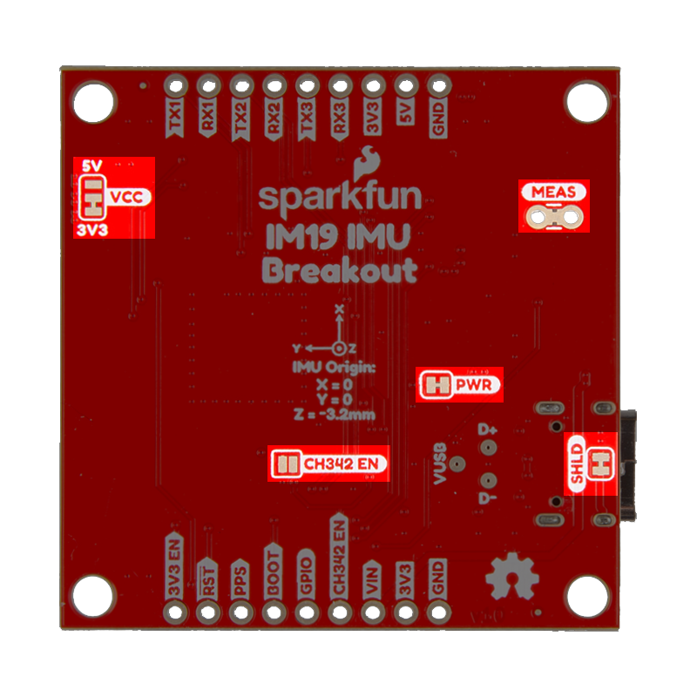
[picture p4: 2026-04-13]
static/img/hookup_guide/jumpers.png

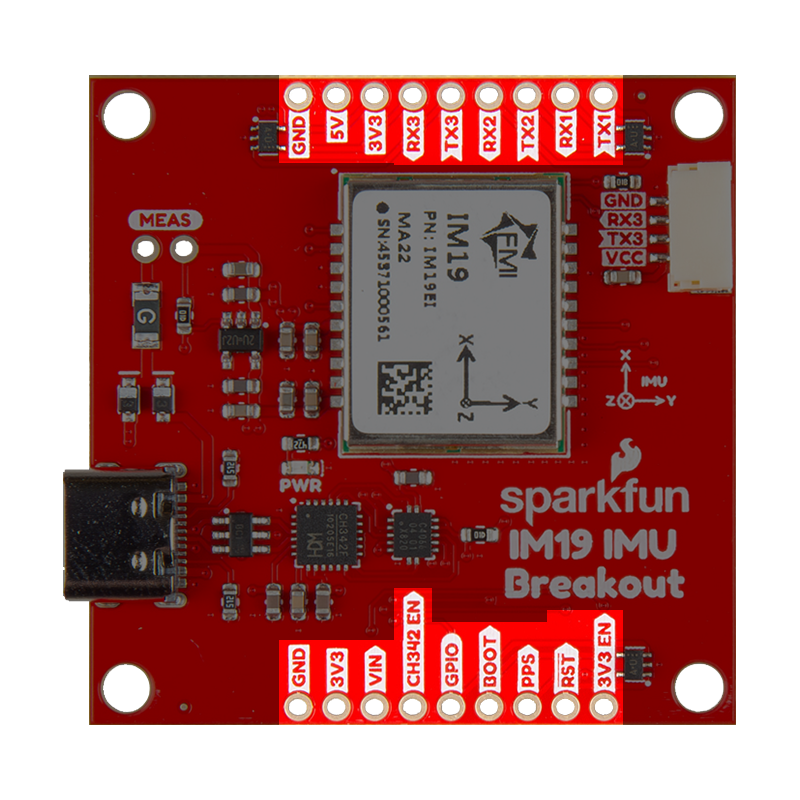
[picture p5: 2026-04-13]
static/img/hookup_guide/headers.png

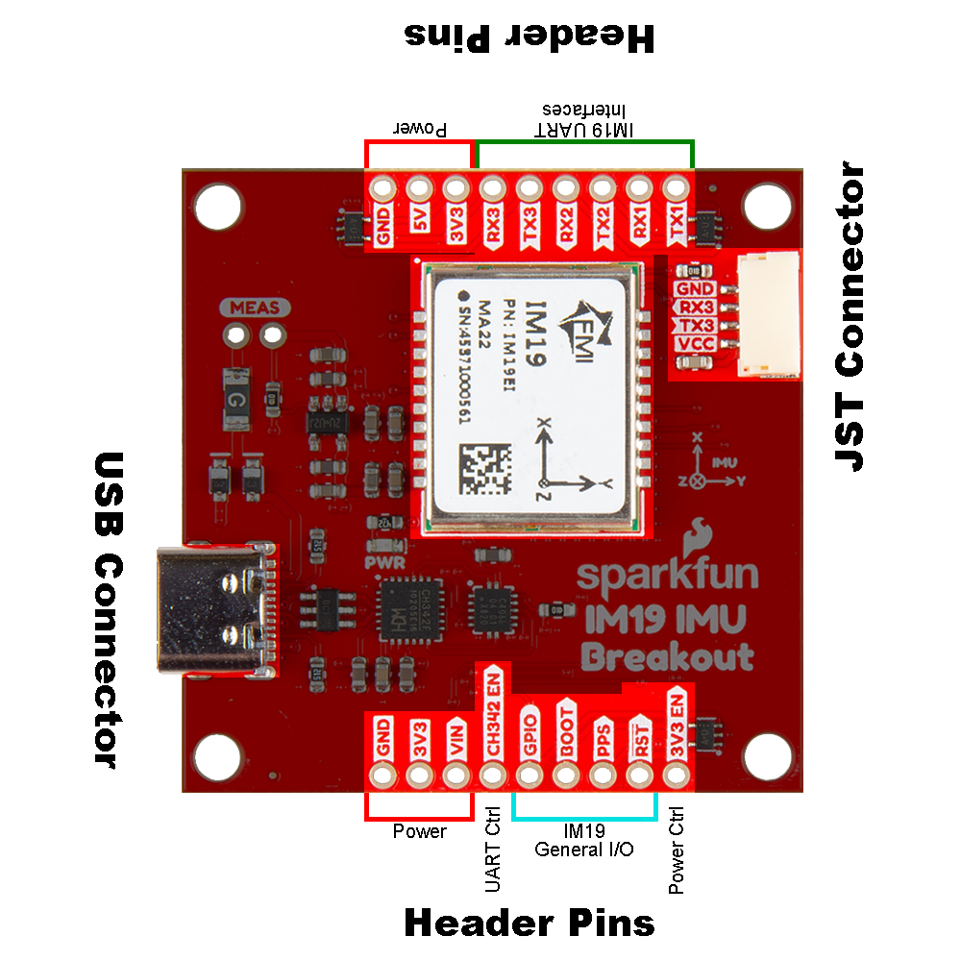
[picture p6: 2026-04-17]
static/img/hookup_guide/layout.png

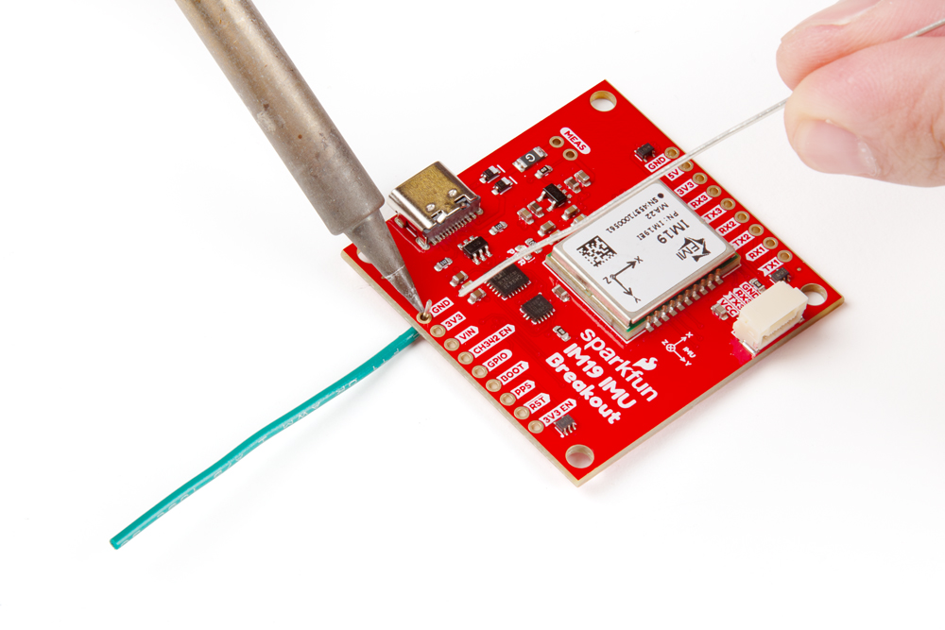
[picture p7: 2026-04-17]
static/img/hookup_guide/assembly-wires.jpg

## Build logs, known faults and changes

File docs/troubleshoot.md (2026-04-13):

---
title: Troubleshoot
description: A compilation of support tips for this product
---

## SparkFun Forum
::::warning[Technical Support]
If you need technical assistance or more information on a product that is not working as you expected, we recommend heading on over to the [SparkFun Forums](https://community.sparkfun.com). The **Issues** page of the GitHub repository is not where users should seek assistance.

:::info[Account Registration Required]
For your first visit to our forum, you'll need to create a [Forum Account](https://community.sparkfun.com/signup) to post questions.
:::

::::

## Tilt-Compensation

### Configuration Requirements

- Access to the UART interfaces of the IM19 attitude module
	- By default, the `UART1` and `UART3` ports can be used to configure the IM19 attitude module and receive the tilt compensated position

		:::note[Data Protocol]
		The tilt-compensated position is transmitted in a proprietary data format using `FMI*` messages. The output of these messages also needs to be enabled.
		:::

- Access to configure the UART interface and PPS signal that are transmitting from the GNSS receiver to the IM19 attitude module

	::::note[UART Interface]
	For the UART interface of the GNSS receiver that is connected to the IM19 attitude module, users will need to configure the UART port for the following settings:

	- Baudrate: 115200bps
	- Output NMEA Messages: `GPGGA`, `GPRMC`, and `GPGST`
	- Solution Rate: **5Hz**

	<br />

	:::tip
	The IM19 attitude module requires RTK GNSS position data. That is to say, the GNSS receiver must be transmitting position data, while it has an **RTK Fix**.
	:::

	::::

	:::note[PPS Signal]
	The timing of the `PPS` signal from the GNSS receiver should be **1Hz**
	:::

- The location of the **ARC** of the GNSS antenna with respect to the IMU's origin; and the vector between the **APC** and survey point.

	:::info
	For information on the antenna reference point (ARP) and antenna phase center (APC), check out this useful [tutorial by Septentrio](https://customersupport.septentrio.com/s/article/ARP-APC-offsets).
	:::

## AT-Commands

- The AT-commands are case-sensitive double check that all characters are capitalized.
- The AT-commands need to be sent in a single string.
	- It is recommended to utilize a terminal emulator that sends a string of characters, instead of each character as they are typed. For example, the Serial Monitor in the Arduino IDE.
- Verify the baud rate is set to **115200bps**

### Save & Reset
Don't forget to save any parameter changes and reset the device, as necessary:

| AT Command | Description |
| :--- | :--- |
| `AT+SAVE_ALL` | Save the parameters |
| `AT+SYSTEM_RESET` | System reset |

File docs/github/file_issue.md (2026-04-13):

---
title: File an Issue
description: Spot something wrong? Please let us know
---

## Need Assistance?

::::warning[Need Help?]
If you need technical assistance or more information on a product that is not working as you expected, we recommend heading on over to the [SparkFun Forums](https://community.sparkfun.com). The **Issues** page of the GitHub repository is not where users should seek assistance.

:::info[Account Registration Required]
For your first visit to our forum, you'll need to create a [Forum Account](https://community.sparkfun.com/signup) to post questions.
:::

::::

## Did we make a mistake?
Spot something wrong? Please let us know. 

### Discrepancies in the Documentation
All of our documentation can be modified by you! Please help us make it better.

- The documentation files for these pages are contained in the [`docs` folder](https://github.com/sparkfun/SparkFun_IM19_IMU_Breakout/tree/main/docs) of the [SparkFun IM19 IMU Breakout repository](https://github.com/sparkfun/SparkFun_IM19_IMU_Breakout).

#### 🔍 Spot something wrong?
If a section of the documentation is incorrect, please [open an issue](https://github.com/sparkfun/SparkFun_IM19_IMU_Breakout/issues) and let us know.

#### Do you have a suggested correction?

1. With a GitHub account, [fork this repository](https://github.com/sparkfun/SparkFun_IM19_IMU_Breakout/fork).
2. Add your correction(s) or improvement(s) to the markdown file(s)
3. File a pull request with your changes, and enjoy making the ~~words~~ ~~worlds~~ world a better place.
	- Once received, the documentation specialist will automatically be notified.
	- We will review your suggested improvement(s) to make sure they are correct and fit within our documentation standards.

### Problems in the Hardware Design
All of our designs are open-source! Please help us make it better.

- Our board design files are contained in the `/Hardware` directories of the [SparkFun IM19 IMU Breakout repository](https://github.com/sparkfun/SparkFun_IM19_IMU_Breakout).

#### Does something not make sense? 🤔
If part of the design is confusing, please [open an issue](https://github.com/sparkfun/SparkFun_IM19_IMU_Breakout/issues) and let us know.

#### Did we forget to include an important function of the board? 🤦
If part of the board's functionality is missing, please [open an issue](https://github.com/sparkfun/SparkFun_IM19_IMU_Breakout/issues) and file a feature request.

:::tip[Design Considerations]
Please keep in mind that we may intentionally exclude certain functions of the board to meet our product design requirements.

- *For example, our Qwiic Micro boards are intended to fit on a small board layout and only use I^2^C communication; therefore, we may not have the SPI and interrupt pins available for users.*
:::

#### Do you wish to contribute directly to improving the board design?

1. With a GitHub account, [fork this repository](https://github.com/sparkfun/SparkFun_IM19_IMU_Breakout/fork).
2. Add your design augmentation(s)
3. File a pull request with your changes, and enjoy making the ~~words~~ ~~worlds~~ world a better place.
	1. Once received, the engineer in charge of the original design will automatically be notified.
	2. We will review your suggested improvement(s) to verify that they are within our board design standards and meet our product design requirements.
	3. If approved, we will flag these changes for our next board revision. Congrats! 🍻

		:::info
		Even if your suggestion is accepted, these changes may not be immediately available for purchase. We may have to cycle through our current product inventory first.
		:::

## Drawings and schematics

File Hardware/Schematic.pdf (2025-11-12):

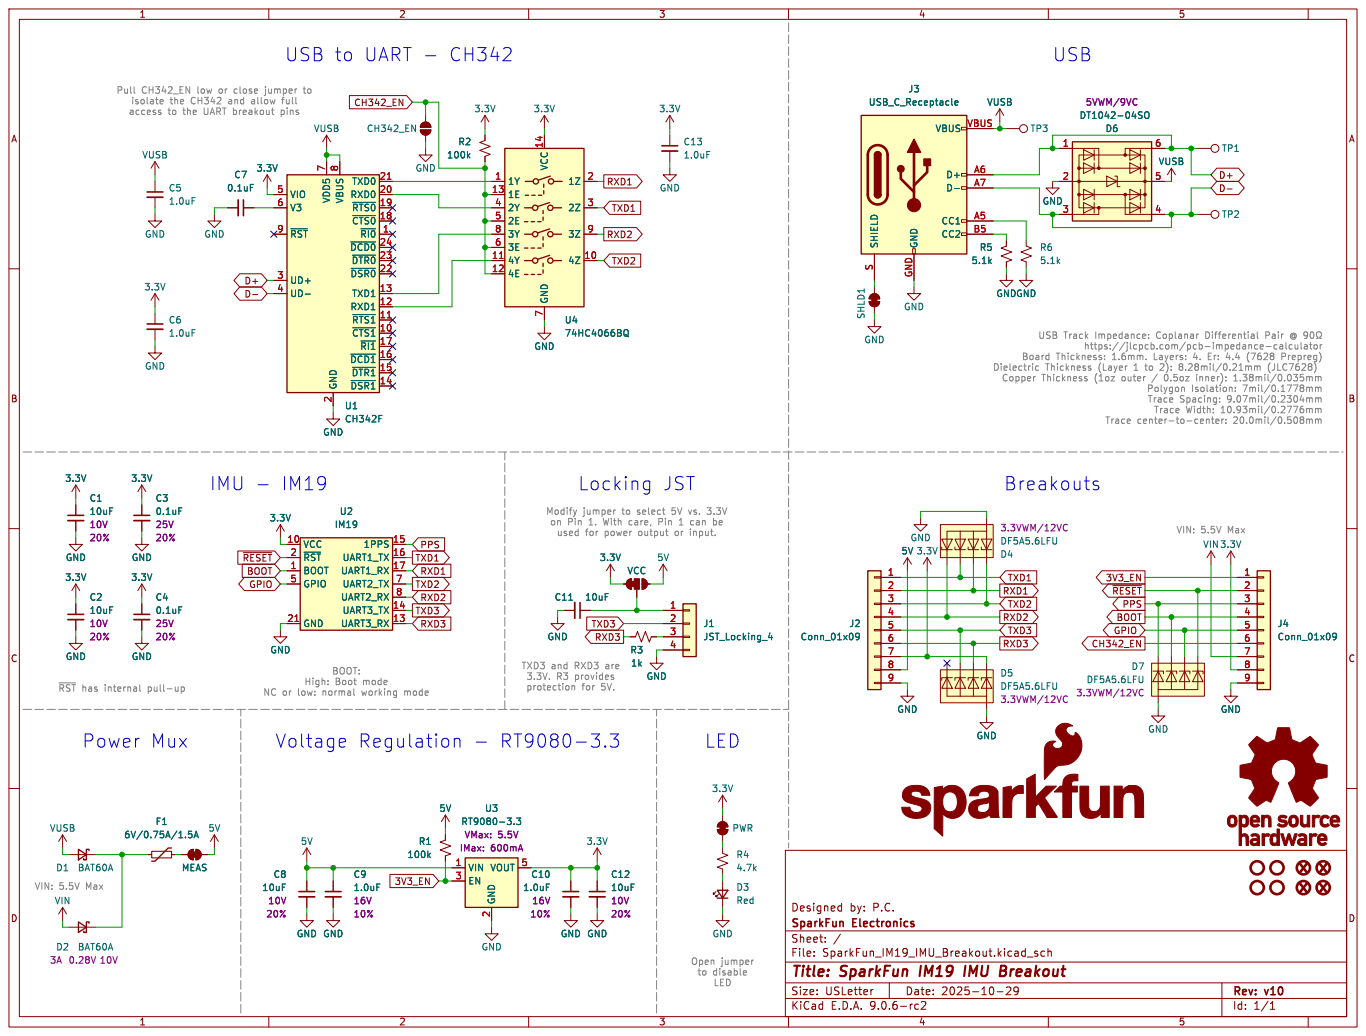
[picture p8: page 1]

Pull CH342_EN low or close jumper to

Copper Thickness (1oz outer / 0.5oz inner): 1.38mil/0.035mm

Modify jumper to select 5V vs. 3.3V
on Pin 1. With care, Pin 1 can be
used for power output or input.
JST_Locking_4 R4

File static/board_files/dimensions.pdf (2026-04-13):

# 0.10 in 0.10 in

# 0.10 in 0.10 in

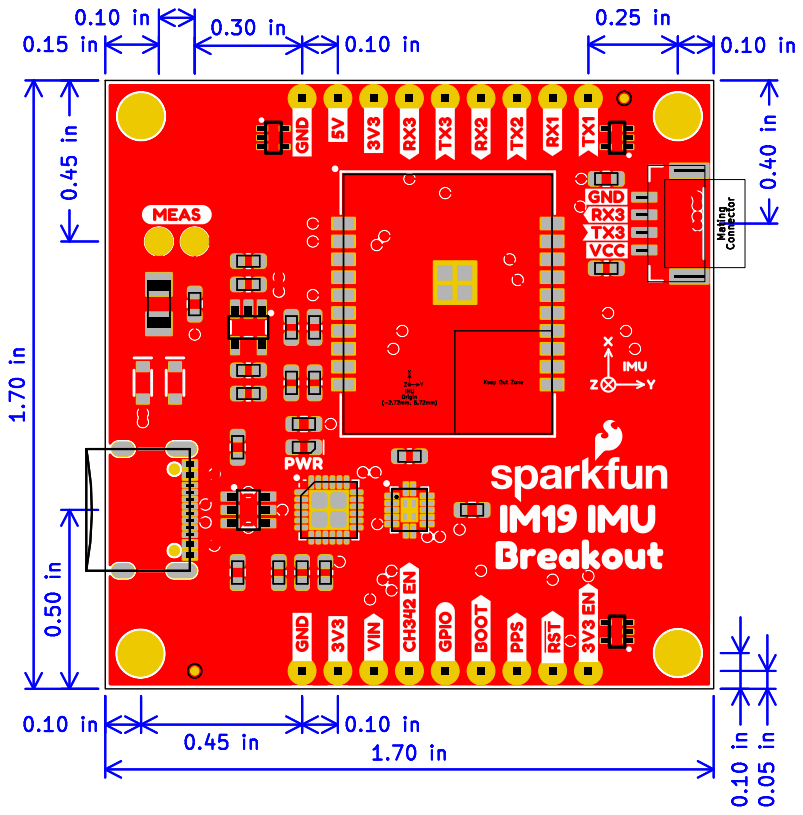
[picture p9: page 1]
Mating Connector Mating Connector; IMU; 5.72mm) ZOrigin

X Keep Out Zone

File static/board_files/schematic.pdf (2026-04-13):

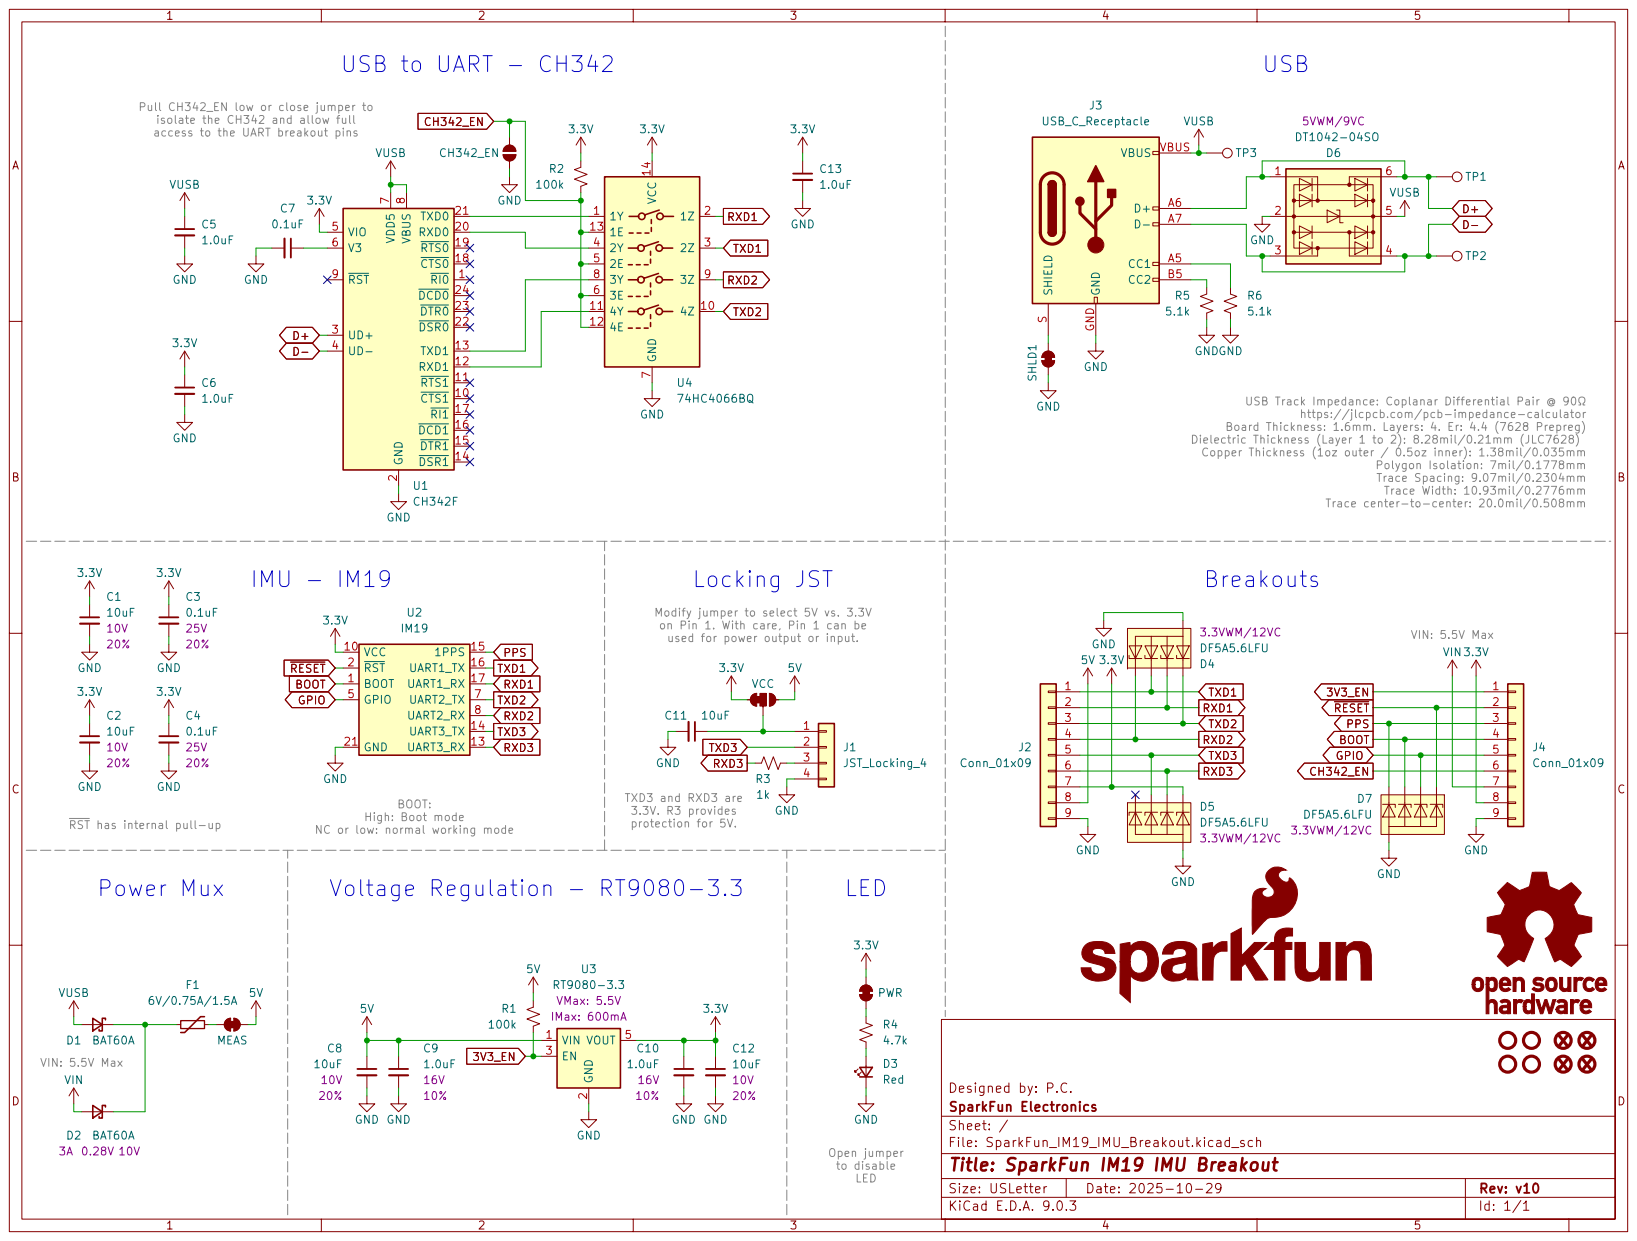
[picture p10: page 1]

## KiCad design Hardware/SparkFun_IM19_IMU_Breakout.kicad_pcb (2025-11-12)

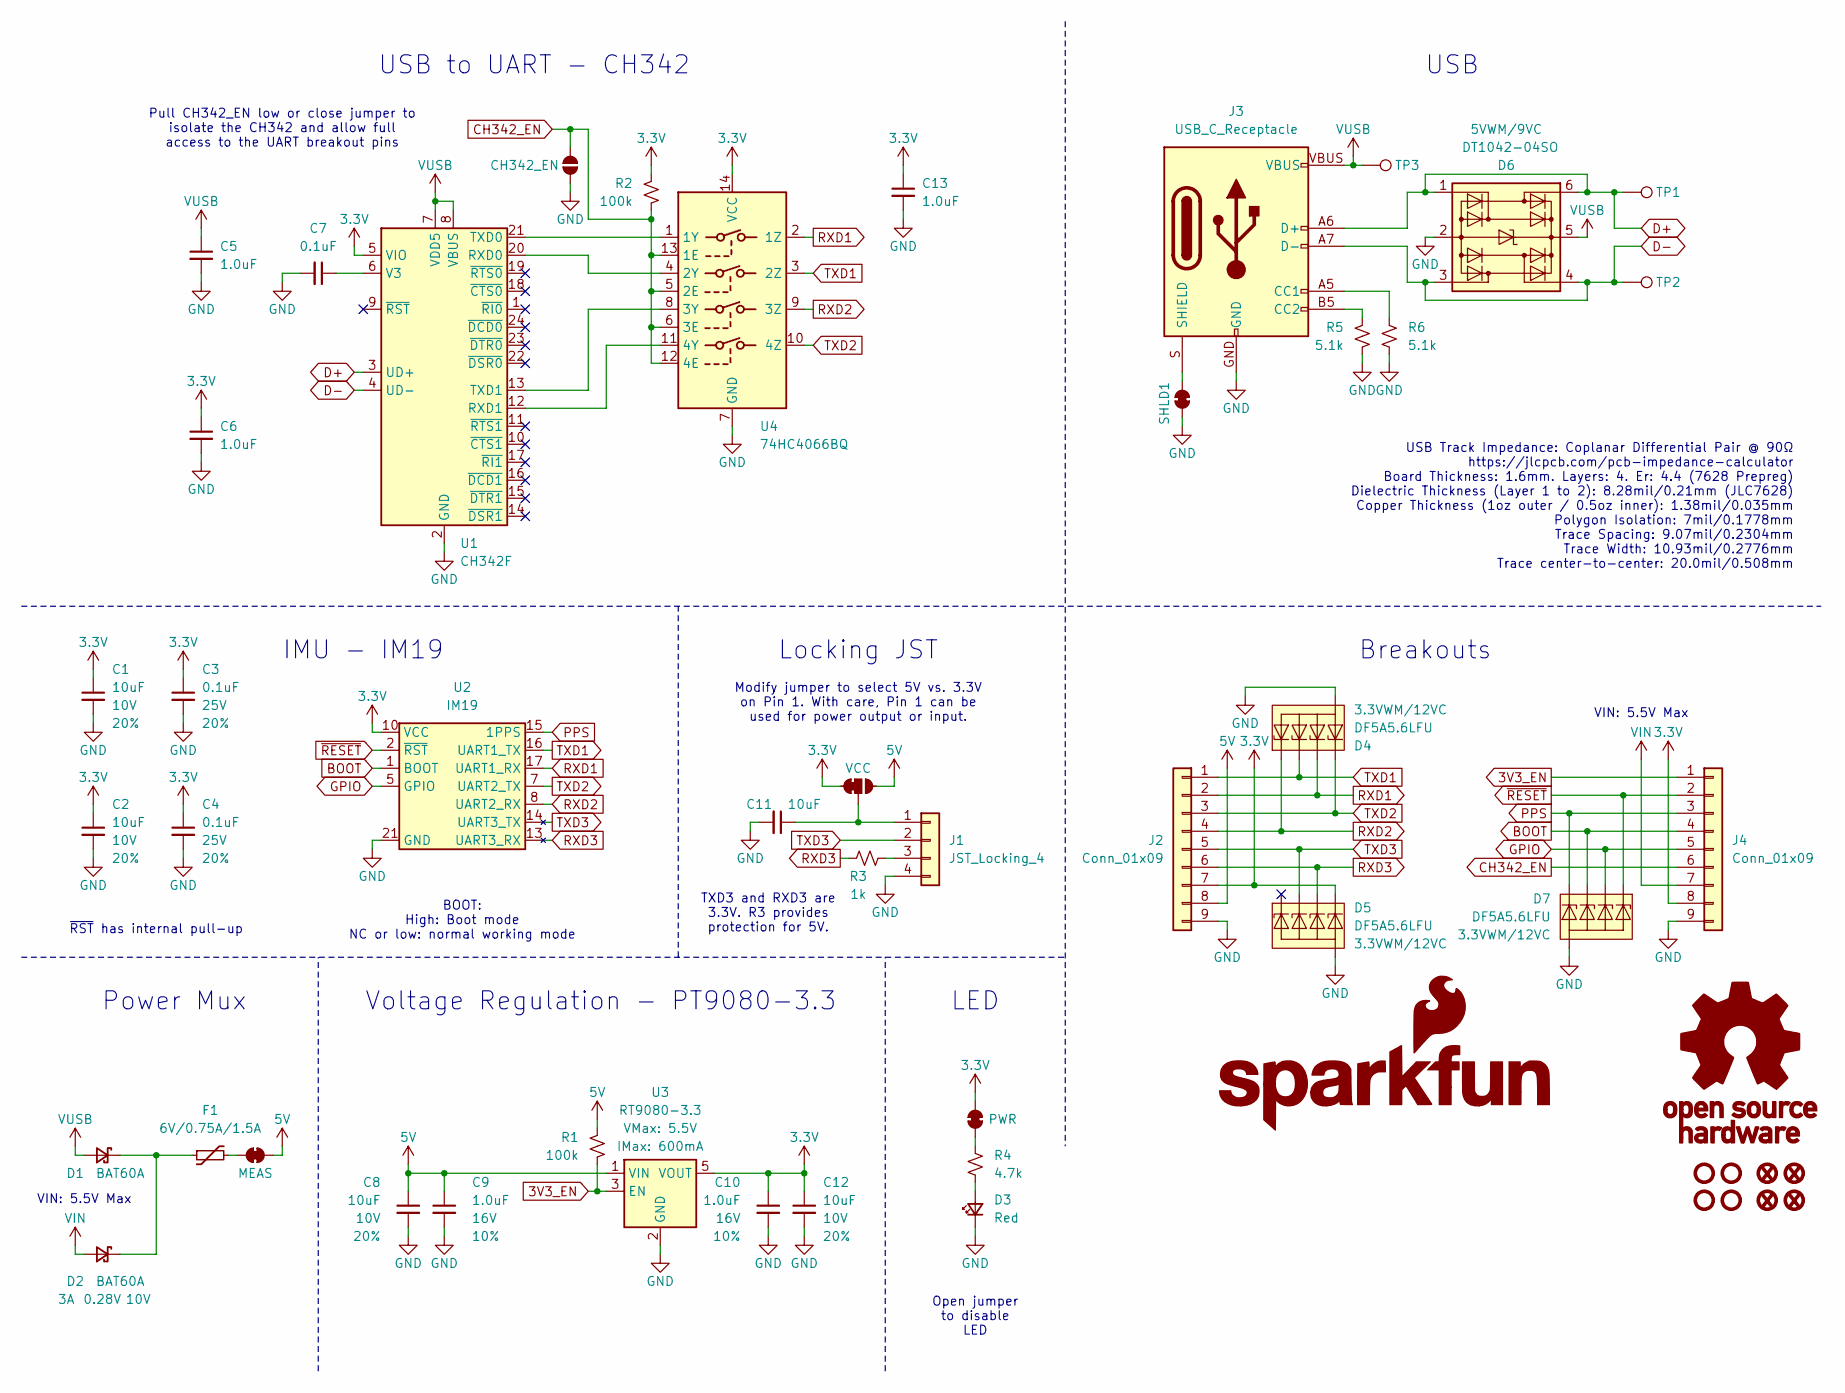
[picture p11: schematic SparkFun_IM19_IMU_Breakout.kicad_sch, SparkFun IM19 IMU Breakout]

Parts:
C1, C2, C8, C11, C12: 10uF; C_0603_1608Metric; Voltage 10V; Tolerance 20%
C3, C4, C7: 0.1uF; C_0603_1608Metric; Voltage 25V; Tolerance 20%
C5, C6, C9, C10, C13: 1.0uF; C_0603_1608Metric; Voltage 16V; Tolerance 10%
CH342_EN.1: CH342_EN; Jumper_2_NO
D1, D2: BAT60A; SOD-323
D3: Red; LED_0603_1608Metric_Red
D4, D5, D7: DF5A5.6LFU; SOT-353; Rating 3.3VWM/12VC
D6: DT1042-04SO; SOT23-6; Rating 5VWM/9VC
F1: 6V/0.75A/1.5A; 1206
FID1, FID2, FID3, FID4: Fiducial_0.5mm; Fiducial_0.5mm_Mask1mm
G1: SparkFun_Logo
G2: OSHW_Logo; Creative_Commons_License
J1: JST_Locking_4; JST_1x04_P1.25mm_Locking_Horizontal_SMD
J2, J4: Conn_01x09; 1x09_P2.54mm
J3: USB_C_Receptacle; USB-C_16
JP1: MEAS; Jumper_2_PTH_SMD_Combo-NC
PWR.1: PWR; Jumper_2_NC_Trace
R1, R2: 100k; R_0603_1608Metric
R3: 1k; R_0603_1608Metric
R4: 4.7k; R_0603_1608Metric
R5, R6: 5.1k; R_0603_1608Metric
SHLD1: Jumper_2_NC_Trace
ST1, ST2, ST3, ST4: Standoff
TP1, TP2, TP3: 1.25mm; TestPoint-1.25mm
U1: CH342F; QFN-24-1EP_4x4mm_P0.5mm_EP2.7x2.7mm
U2: IM19
U3: RT9080-3.3; SOT23-5
U4: 74HC4066BQ; QFN-14_2.5x3mm_P0.5mm_EP1x1.5mm
VCC.1: VCC; Jumper_3_NC-1_Trace

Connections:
3.3V: C1.1, C2.1, C3.1, C4.1, C6.1, C10.1, C12.1, C13.1, D5.5 (K4), J2.7, J4.8, PWR.1.2 (B), R2.2, U1.5 (VIO), U2.6 (VCC), U2.10 (VCC), U3.5 (VOUT), U4.14 (VCC), VCC.1.1 (A)
3V3_EN: J4.1, R1.1, U3.3 (EN)
5V: C8.1, C9.1, J2.8, JP1.2 (B), R1.2, U3.1 (VIN), VCC.1.3 (C)
BOOT: D7.4 (K3), J4.4, U2.1 (BOOT)
CH342_EN: CH342_EN.1.2 (B), J4.6, R2.1, U4.5 (2E), U4.6 (3E), U4.12 (4E), U4.13 (1E)
D+: D6.1 (I/O1), D6.6 (I/O4), J3.A6 (D+), J3.B6 (D+), TP1.1, U1.3 (UD+)
D-: D6.3 (I/O2), D6.4 (I/O3), J3.A7 (D-), J3.B7 (D-), TP2.1, U1.4 (UD-)
GND: C1.2, C2.2, C3.2, C4.2, C5.2, C6.2, C7.2, C8.2, C9.2, C10.2, C11.2, C12.2, C13.2, CH342_EN.1.1 (A), D3.1 (K), D4.2 (A), D5.2 (A), D6.2 (GND), D7.2 (A), J1.4, J2.9, J3.GND, J4.9, R5.1, R6.1, SHLD1.1 (A), U1.2 (GND), U1.25 (GND), U2.3 (GND), U2.4 (GND), U2.9 (GND), U2.18 (GND), U2.21 (GND), U3.2 (GND), U4.7 (GND)
GPIO: D7.3 (K2), J4.5, U2.5 (GPIO)
unnamed: D1.1 (K), D2.1 (K), F1.1
unnamed: D3.2 (A), R4.1
unnamed: C11.1, J1.1, VCC.1.2 (B)
unnamed: J1.3, R3.2
unnamed: J3.A5 (CC1), R6.2
unnamed: J3.B5 (CC2), R5.2
unnamed: J3.S (SHIELD), SHLD1.2 (B)
unnamed: F1.2, JP1.1 (A)
unnamed: PWR.1.1 (A), R4.2
unnamed: U1.20 (RXD0), U4.4 (2Y)
unnamed: U1.12 (RXD1), U4.11 (4Y)
unnamed: U1.21 (TXD0), U4.1 (1Y)
unnamed: U1.13 (TXD1), U4.8 (3Y)
unnamed: C7.1, U1.6 (V3)
PPS: D7.5 (K4), J4.3, U2.15 (1PPS)
RXD1: D4.4 (K3), J2.2, U2.17 (UART1_RX), U4.2 (1Z)
RXD2: D4.1 (K1), J2.4, U2.8 (UART2_RX), U4.9 (3Z)
RXD3: D5.4 (K3), J2.6, R3.1, U2.13 (UART3_RX)
TXD1: D4.3 (K2), J2.1, U2.16 (UART1_TX), U4.3 (2Z)
TXD2: D4.5 (K4), J2.3, U2.7 (UART2_TX), U4.10 (4Z)
TXD3: D5.3 (K2), J1.2, J2.5, U2.14 (UART3_TX)
VIN: D2.2 (A), J4.7
VUSB: C5.1, D1.2 (A), D6.5 (VCC), J3.VBUS, TP3.1, U1.7 (VDD5), U1.8 (VBUS)
~RESET: D7.1 (K1), J4.2, U2.2 (~RST)

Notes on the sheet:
Modify jumper to select 5V vs. 3.3V on Pin 1. With care, Pin 1 can be used for power output or input.
Power Mux
BOOT: High: Boot mode NC or low: normal working mode
IMU - IM19
USB
Breakouts
TXD3 and RXD3 are 3.3V. R3 provides protection for 5V.
USB to UART - CH342
Pull CH342_EN low or close jumper to isolate the CH342 and allow full access to the UART breakout pins
Voltage Regulation - PT9080-3.3
~{RST} has internal pull-up
USB Track Impedance: Coplanar Differential Pair @ 90Ω https://jlcpcb.com/pcb-impedance-calculator Board Thickness: 1.6mm. Layers: 4. Er: 4.4 (7628 Prepreg) Dielectric Thickness (Layer 1 to 2): 8.28mil/0.21mm (JLC7628) Copper Thickness (1oz outer / 0.5oz inner): 1.38mil/0.035mm Polygon Isolation: 7m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
Open jumper to disable LED
Locking JST
LED
VIN: 5.5V Max

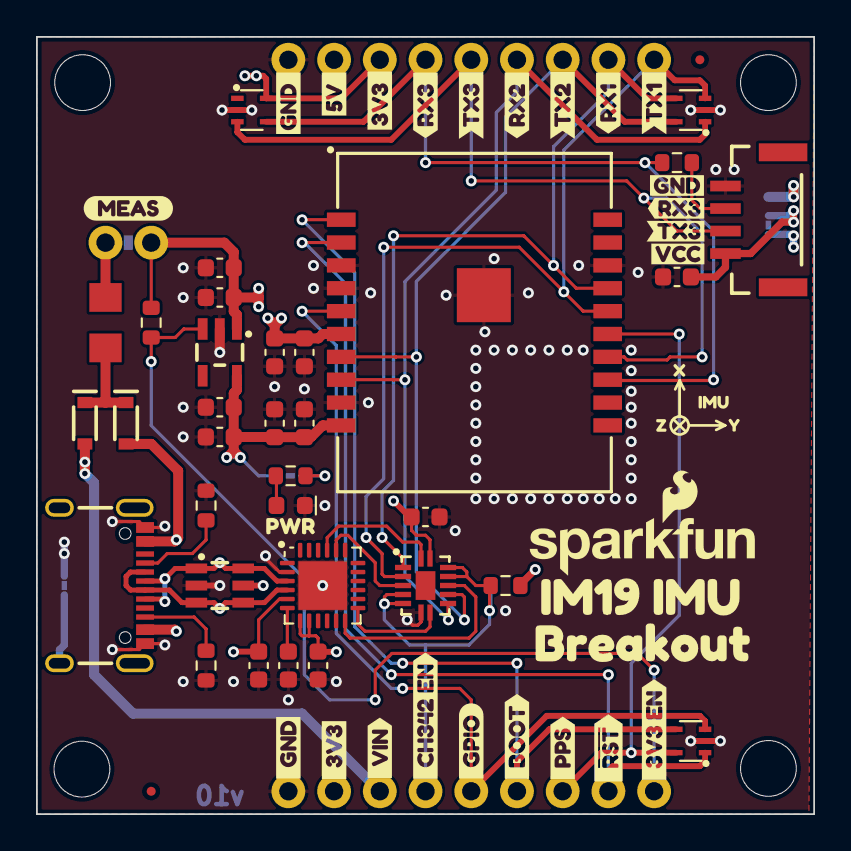
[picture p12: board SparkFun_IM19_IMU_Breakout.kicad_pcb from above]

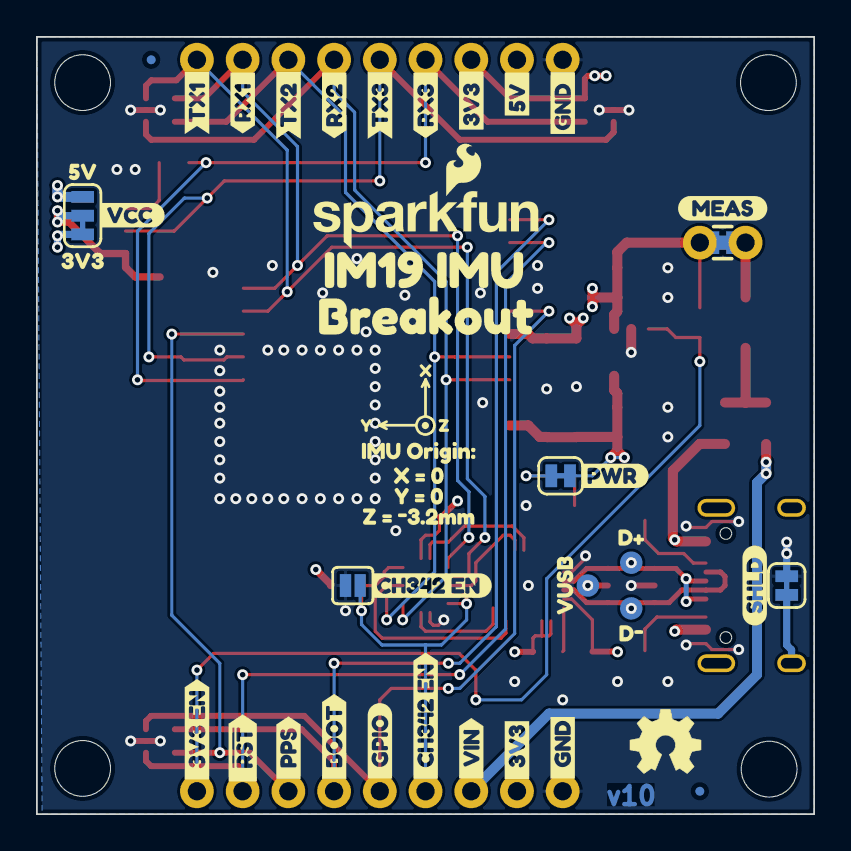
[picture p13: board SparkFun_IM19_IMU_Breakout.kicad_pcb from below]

Board: 4 copper layers, 43.2 x 43.2 mm, 120 parts (48 on the bottom side), 33 nets.

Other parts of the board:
Ref**: Val**; OSHW_Logo_4mm
kibuzzard-67FFA928: G***; kibuzzard-67FFA928
kibuzzard-67FFB45E, kibuzzard-67FFB45E#2: G***; kibuzzard-67FFB45E
kibuzzard-67FFB46A, kibuzzard-67FFB46A#2: G***; kibuzzard-67FFB46A
kibuzzard-67FFB450, kibuzzard-67FFB450#2: G***; kibuzzard-67FFB450
kibuzzard-68F5D5EE, kibuzzard-68F5D5EE#2: G***; kibuzzard-68F5D5EE
kibuzzard-68F5D6B2, kibuzzard-68F5D6B2#2: G***; kibuzzard-68F5D6B2
kibuzzard-68F5D6C3, kibuzzard-68F5D6C3#2: G***; kibuzzard-68F5D6C3
kibuzzard-68F5D6DA, kibuzzard-68F5D6DA#2: G***; kibuzzard-68F5D6DA
kibuzzard-68F5D9B9: G***; kibuzzard-68F5D9B9
kibuzzard-68F5D9CC: G***; kibuzzard-68F5D9CC
kibuzzard-68F5D9E8: G***; kibuzzard-68F5D9E8
kibuzzard-68F5D71D, kibuzzard-68F5D71D#2: G***; kibuzzard-68F5D71D
kibuzzard-68F5D97A: G***; kibuzzard-68F5D97A
kibuzzard-68F5D651, kibuzzard-68F5D651#2: G***; kibuzzard-68F5D651
kibuzzard-68F5D664, kibuzzard-68F5D664#2: G***; kibuzzard-68F5D664
kibuzzard-68F5D677, kibuzzard-68F5D677#2: G***; kibuzzard-68F5D677
kibuzzard-68F5D706, kibuzzard-68F5D706#2: G***; kibuzzard-68F5D706
kibuzzard-68F5DA6F, kibuzzard-68F5DA6F#2: G***; kibuzzard-68F5DA6F
kibuzzard-68F5DABB, kibuzzard-68F5DABB#2: G***; kibuzzard-68F5DABB
kibuzzard-68F5DAD8, kibuzzard-68F5DAD8#2: G***; kibuzzard-68F5DAD8
kibuzzard-68F5DB0E, kibuzzard-68F5DB0E#2: G***; kibuzzard-68F5DB0E
kibuzzard-68F5DB1B: G***; kibuzzard-68F5DB1B
kibuzzard-68F5DB2C, kibuzzard-68F5DB2C#2: G***; kibuzzard-68F5DB2C
kibuzzard-68F5DB3E, kibuzzard-68F5DB3E#2: G***; kibuzzard-68F5DB3E
kibuzzard-68F5DB51, kibuzzard-68F5DB51#2: G***; kibuzzard-68F5DB51
kibuzzard-68F5DB62, kibuzzard-68F5DB62#2: G***; kibuzzard-68F5DB62
kibuzzard-68F5DDAB: G***; kibuzzard-68F5DDAB
kibuzzard-68F5DDD0: G***; kibuzzard-68F5DDD0
kibuzzard-68F5DDF5: G***; kibuzzard-68F5DDF5
kibuzzard-68F5DE2E: G***; kibuzzard-68F5DE2E
kibuzzard-68F5E0B5, kibuzzard-68F5E0B5#2: G***; kibuzzard-68F5E0B5
kibuzzard-68F5E8F0: G***; kibuzzard-68F5E8F0
kibuzzard-68F5E8FA: G***; kibuzzard-68F5E8FA
kibuzzard-68F5E9AB: G***; kibuzzard-68F5E9AB
kibuzzard-68F5E9C6: G***; kibuzzard-68F5E9C6
kibuzzard-68F5E9E3: G***; kibuzzard-68F5E9E3
kibuzzard-68F5E094, kibuzzard-68F5E094#2: G***; kibuzzard-68F5E094
kibuzzard-68F5E982: G***; kibuzzard-68F5E982
kibuzzard-68F5EA91, kibuzzard-68F5EA91#2: G***; kibuzzard-68F5EA91
kibuzzard-68F5EC7C: G***; kibuzzard-68F5EC7C
kibuzzard-68F5ECB4: G***; kibuzzard-68F5ECB4
kibuzzard-68F5ECF3: G***; kibuzzard-68F5ECF3
kibuzzard-68F5EDC8: G***; kibuzzard-68F5EDC8
kibuzzard-68F62121: G***; kibuzzard-68F62121

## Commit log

2025-10-17 Initial Hardware commit - WIP
    [SparkFun_IM19_IMU_Breakout.kicad_pcb, SparkFun_IM19_IMU_Breakout.kicad_sch]
2025-10-18 More WIP
    [SparkFun_IM19_IMU_Breakout.kicad_pcb, SparkFun_IM19_IMU_Breakout.kicad_sch]
2025-10-20 Add PWR LED and silk. Ignore -backups
    [SparkFun_IM19_IMU_Breakout.kicad_pcb, SparkFun_IM19_IMU_Breakout.kicad_sch]
2025-10-20 Panelized - ready for review
    [SparkFun_IM19_IMU_Breakout.kicad_pcb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]
2025-11-12 Updates after review
    [SparkFun_IM19_IMU_Breakout.kicad_pcb, SparkFun_IM19_IMU_Breakout.kicad_sch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]
2025-11-12 Correct typo
    [SparkFun_IM19_IMU_Breakout.kicad_sch]
2025-11-12 Rename Schematic
2026-04-08 Add hardware files
    Adds the board design files (schematic, KiCad files, etc.)
    Adds the component documentation (datasheets, manuals, etc.)
2026-04-09 Add Site Generator
    Add default framework for Docusaurus

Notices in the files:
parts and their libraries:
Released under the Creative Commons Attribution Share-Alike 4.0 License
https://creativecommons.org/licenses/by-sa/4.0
